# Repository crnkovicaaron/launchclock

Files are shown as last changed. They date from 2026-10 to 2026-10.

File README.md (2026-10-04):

# Rocket Launch Countdown Clock
A standalone digital countdown clock for rocket launches.
It displays countdown and mission elapsed time, is controlled entirely using a keypad, and requires no external computer or network.
It is built around an ATmega328P microcontroller, DS3231 real-time clock, and MAX7219-driven 7-segment and dot matrix displays.

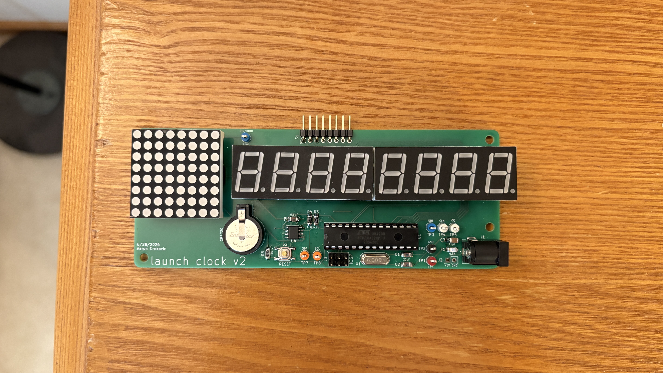
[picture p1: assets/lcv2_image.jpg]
Finished board photo

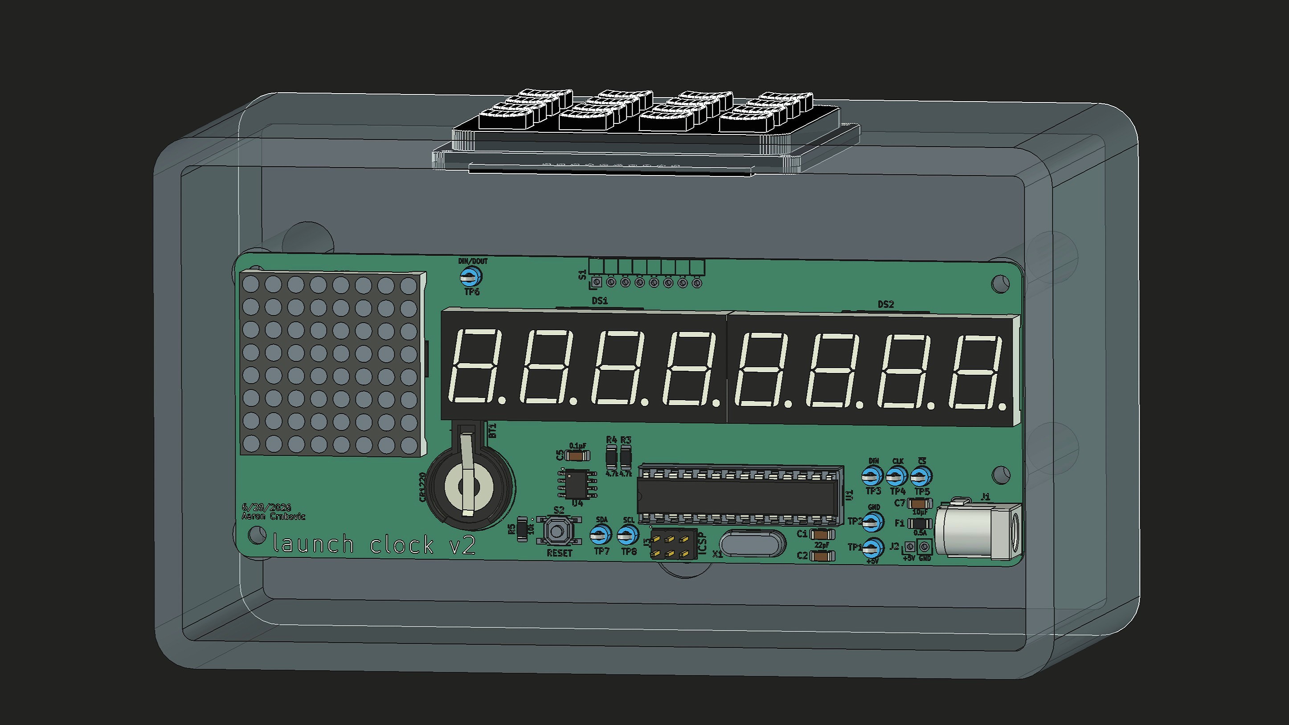
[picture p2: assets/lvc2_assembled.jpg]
Version 2 Box prototype


## Features
- LED Displays: 7-segment for time and dot matrix for mode/status glyphs
- Fully keypad-driven UI
- Launch and current time/date setting (including launch date nudging)
- Countdown pausing
- Low-power sleep mode
- Display brightness control
- Configurable countdown time display format
- Error handling including invalid inputs and RTC power loss

## Hardware
Custom PCB designed in KiCad around an ATmega328P microcontroller.

Key components: 
- **MCU**: ATmega328P
- **RTC**: DS3231M with CR1220 battery backup
- **Displays**: MAX7219-driven dual 4-digit 7-segment (5641AS) and 8x8 dot matrix (1088AS)
- **Input**: 4x4 matrix keypad
- **Power**: 5V DC via 5.5x2.1mm barrel jack (or solder pads to enclosure-mounted barrel jack)
- **Communication**: I²C (RTC) and SPI (display drivers & ISP)
- **Assembly**: Hand soldered; uses both THD and SMD components
- **Enclosure**: Custom 3D printed FreeCAD enclosure is WIP

KiCad schematic and PCB files are under the 'hardware/' directory. Assorted photos can be found under the 'assets/' directory.

Status: Version 2 is completed and functional. Version 3 is WIP.

## Firmware
Written in Arduino C++ (AVR) for the ATmega328P (Arduino Uno).

The firmware implements a keypad-driven state machine that manages countdown/MET display, time/date setting, pause, brightness, sleep, and error handling.

Key elements:

- **Libraries**: RTClib (DS3231), Keypad, LedControl (MAX7219), EEPROM, plus AVR sleep/power utilities
- **Architecture**: Event-driven keypad handling and periodic 1-second time updates; use of mode flags for UI states
- **Displays**: Dual MAX7219 display control with PROGMEM bitmaps
- **Persistence**: Launch time/date stored in EEPROM
- **Power**: Full power-down sleep mode woken by keypad pin-change interrupt
- **Robustness**: Input validation, RTC power-loss detection, and dedicated error states

Source is a single sketch organized into functional blocks (display, input, timekeeping, power, UI modes). Programming is performed via the board's ISP header.

## Development History
### Initial Prototype
This Arduino breadboard prototype was an MVP with the singular goal of counting down to the Artemis II launch, with all work being completed entirely the day prior. It has the 7-segment displays wired directly to an Arduino Mega, uses a DS1307 RTC breakout board, and lacks any inputs.

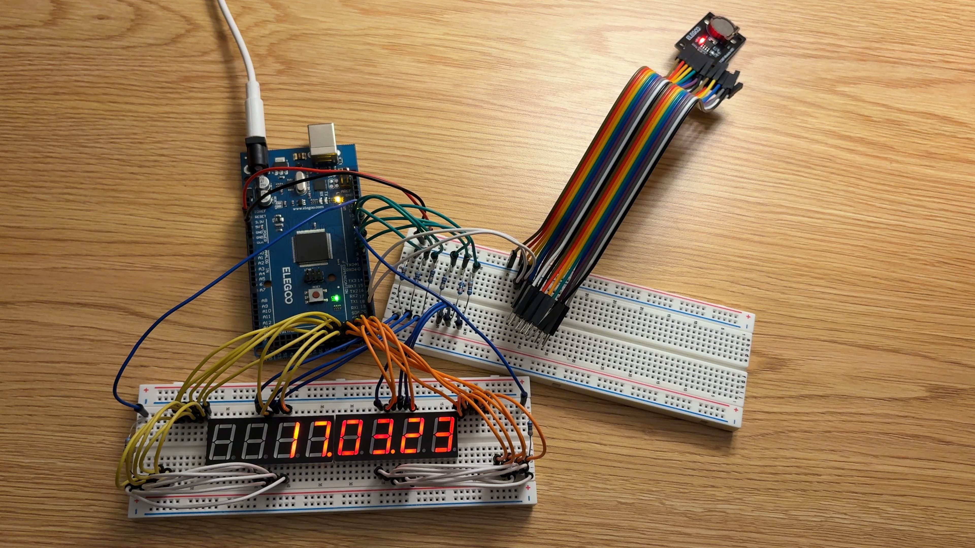
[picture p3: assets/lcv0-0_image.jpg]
Initial prototype photo


### Revised Prototype
This revised prototype contains around a month of additions and improvements to the initial prototype. These include the addition of keypad inputs (out of frame), a dot matrix display, and corrected/improved display wiring. The vast majority of the time since the initial prototype was spent programming the firmware.

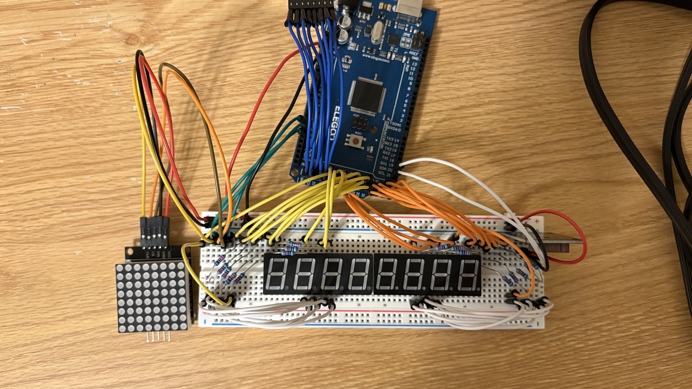
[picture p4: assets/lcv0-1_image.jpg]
Revised prototype photo


### Version 1 PCB
This custom 2-layer PCB mounts directly to an Arduino Mega using header pins, and the 7-segment displays mount to the board. With exception to the SMD resistors, there are essentially no changes to the circuit or its components between the revised prototype and the version 1 board. The main goal of this design was to become familiar with KiCad and PCB design.

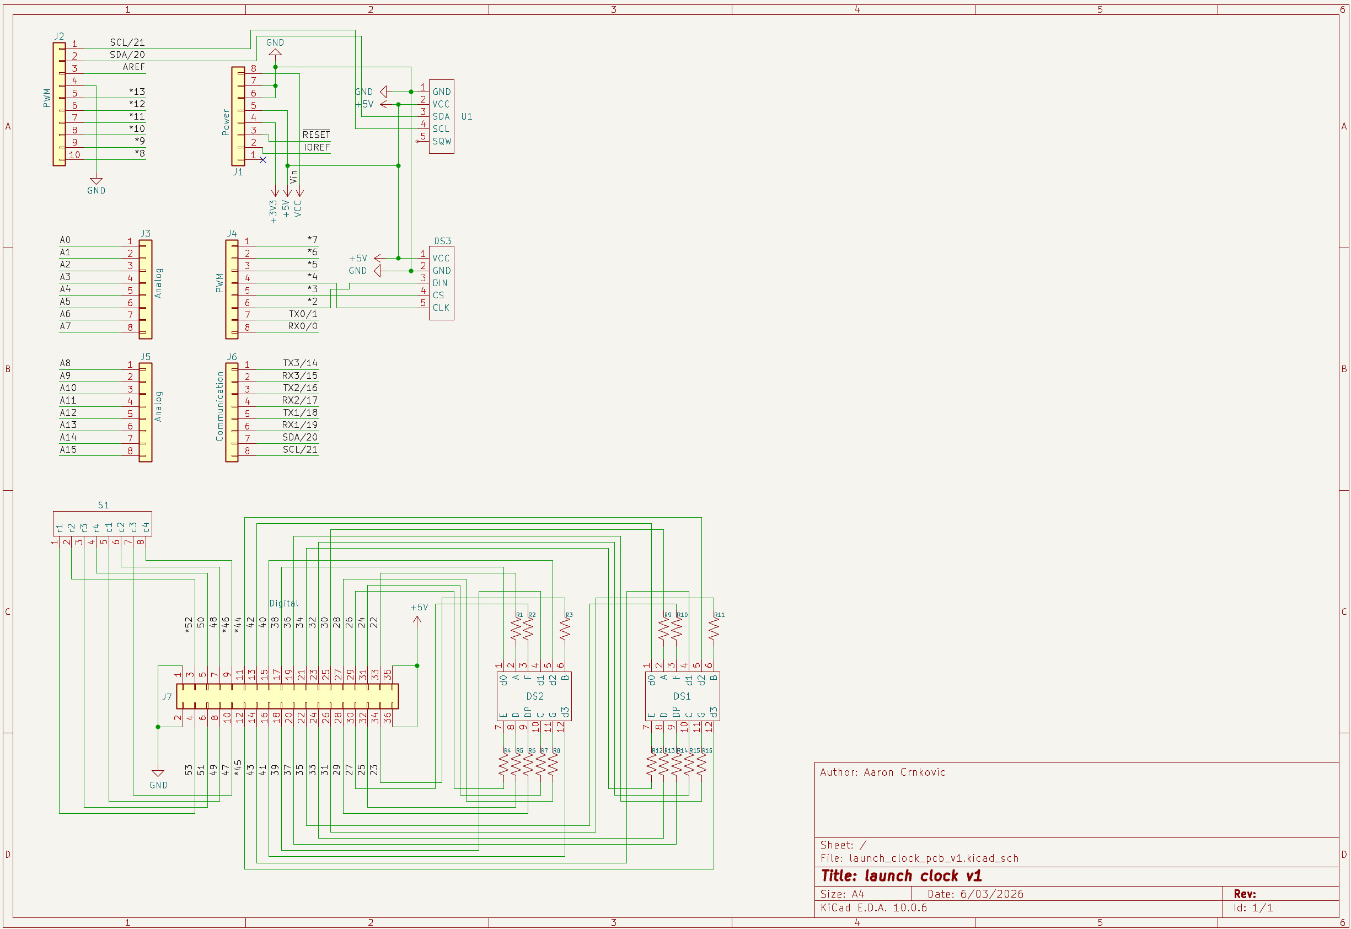
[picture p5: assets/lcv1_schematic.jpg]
Version 1 schematic

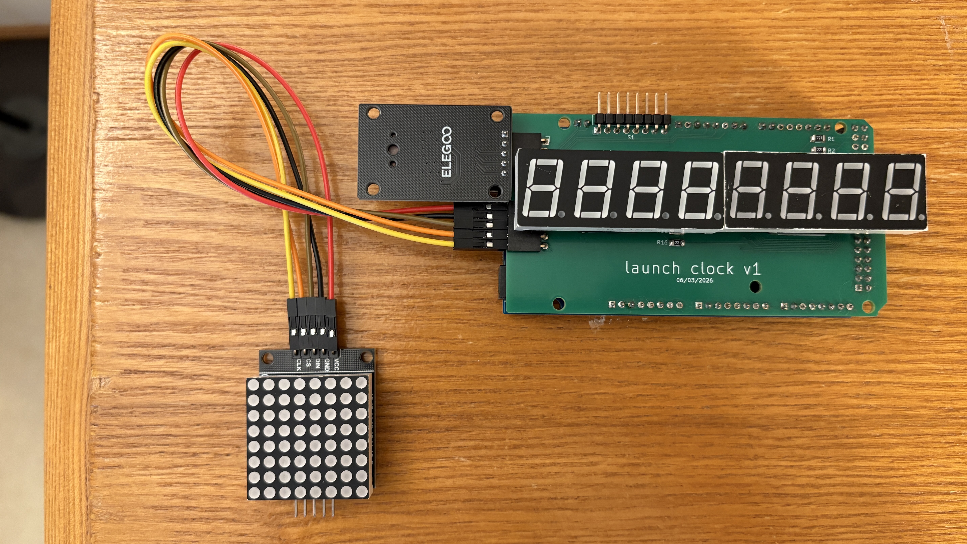
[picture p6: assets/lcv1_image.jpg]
Version 1 image


### Version 2 PCB
The main goal of this version was to eliminate the Arduino and breakout boards by integrating all necessary functionality onto the board itself. This includes driving the 7-segment displays with a MAX7219 in the same manner as the dot matrix to allow the use of an MCU that is easier to solder by hand (instead of the ATmega2560 used on the Arduino Mega). The board is still 2-layers, programming is done via the ISP header, and numerous test points were integrated for troubleshooting and experimentation.

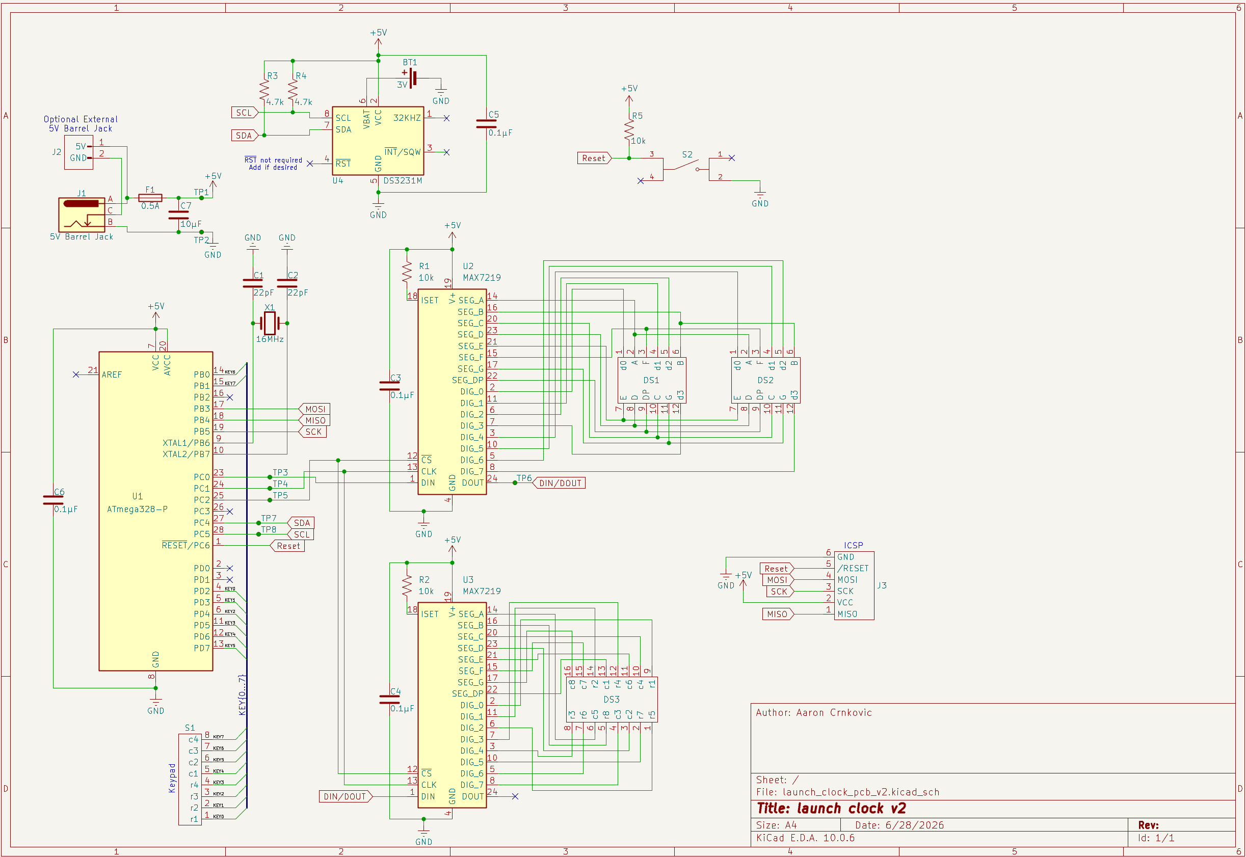
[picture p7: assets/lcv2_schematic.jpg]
Version 2 schematic

Version 2 image

### Version 3 PCB (Work in Progress)
In this version, the barrel jack is superseded by a USB-C port with power and USB 2.0 data functionality. The MCU and display drivers use surface-mount packages in favor of through holes and most passive components are downsized to 0603 parts compared to the 1206 parts on version 2, allowing the total board area to be reduced by 28% compared to version 2. The board was designed to reduce EMI (mainly radiated), which includes switching to a 4-layer board. The revision also addresses numerous smaller issues with the version 2 board, including a soft but audible whine.

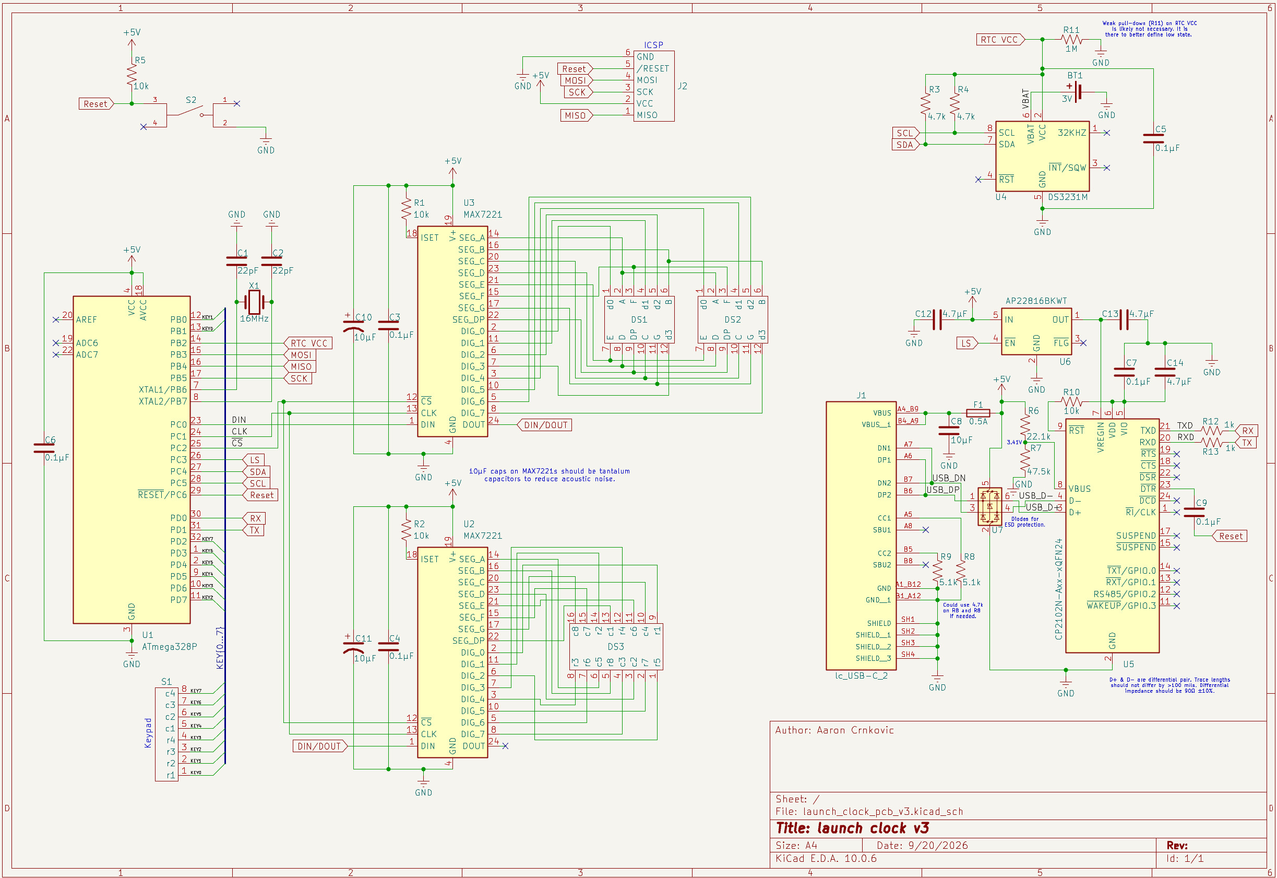
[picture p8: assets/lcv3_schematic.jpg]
Version 3 schematic

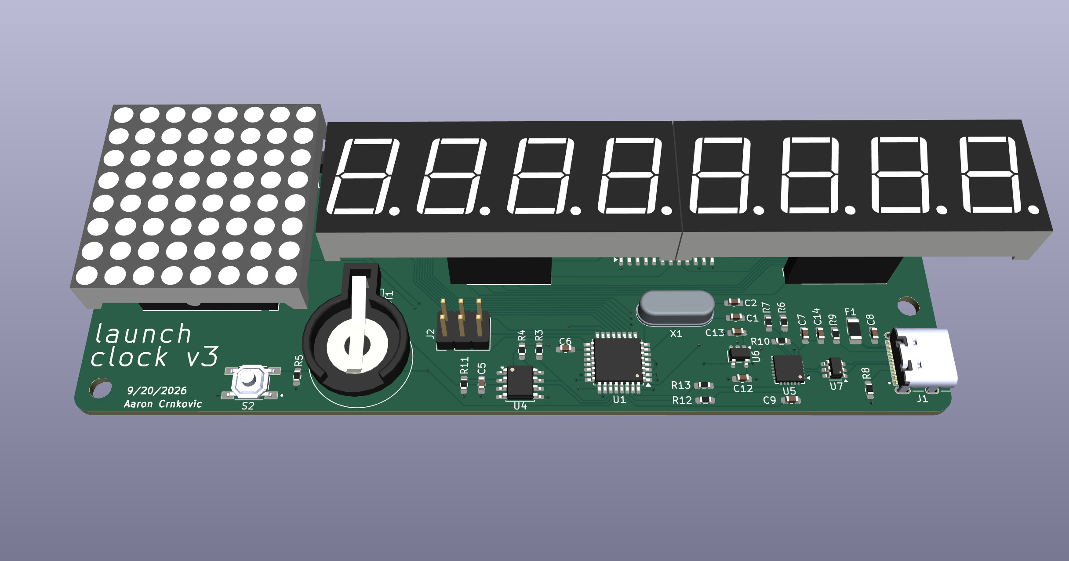
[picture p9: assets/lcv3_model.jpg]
Version 3 KiCad render


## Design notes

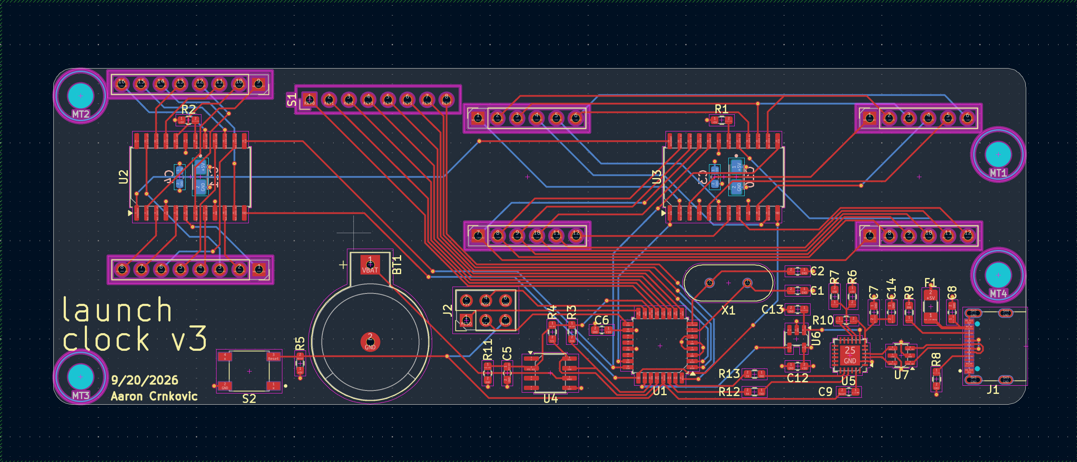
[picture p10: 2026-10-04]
assets/lcv3_pcb.jpg

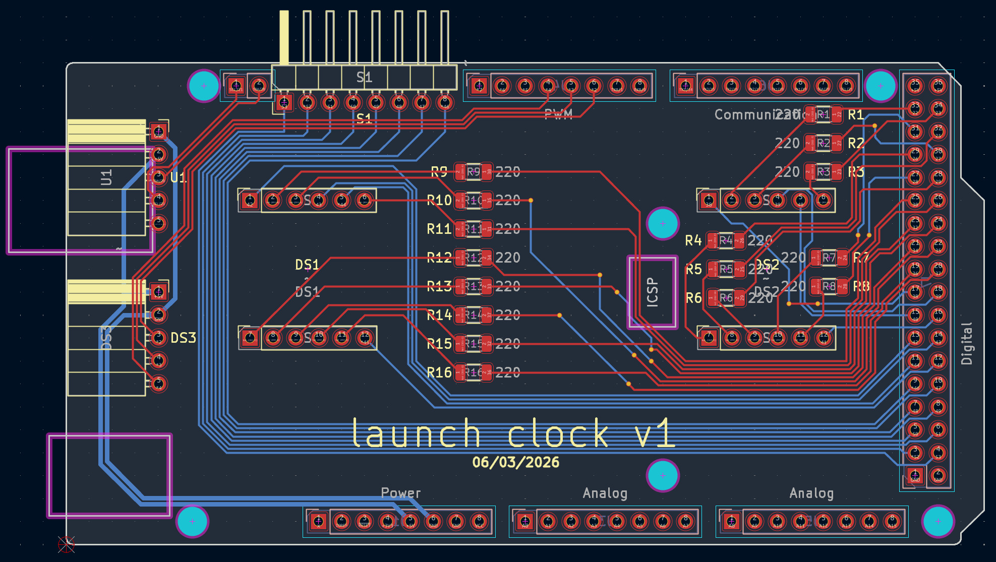
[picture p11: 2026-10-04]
assets/lcv1_pcb.jpg

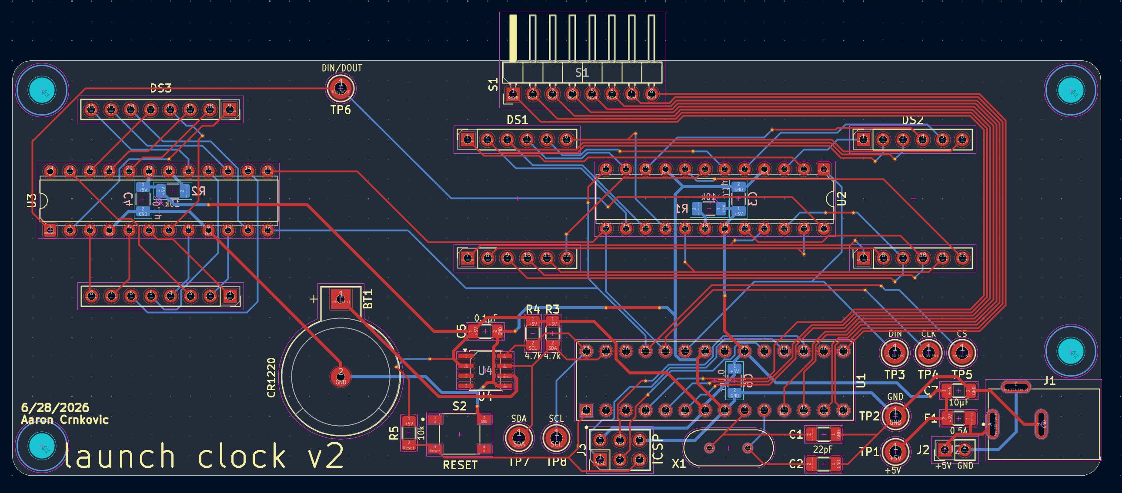
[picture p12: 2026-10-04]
assets/lcv2_pcb.jpg

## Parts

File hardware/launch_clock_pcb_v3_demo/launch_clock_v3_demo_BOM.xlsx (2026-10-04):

Reference | Qty | Value | Footprint | DKPN | Datasheet
BT1 | 1 | 3V | Battery:BatteryHolder_Keystone_500 | 36-500-ND | file:///C:/Users/Aaron%20Crnkovic/Downloads/500%20(1).PDF |  |  |  |  | EN | DKPN | Part | Board Qty | Order Qty | Part Cost | Part Tariff | Net Cost | Net Tariff | Tax | Total Cost | Board Cost | Sales Tax: | 7.50%
C1,C2 | 2 | 22pF | Capacitor_SMD:C_0603_1608Metric_Pad1.08x0.95mm_HandSolder | 490-4942-1-ND | https://pim.murata.com/asset/pim4/ceramicCapacitorSMD/GCM1885C2A220JA16-01A-EN_PDF_CERAMICCAPACITORSMD |  |  |  |  | TRUE | 490-4942-1-ND | 22pF Ceramic Capacitor | 2 | 10 | $0.04 | $0.00463 | $0.44 | $0.05 | $0.04 | $0.49 | $0.10
C3,C4,C5,C6,C7,C9 | 6 | 0.1µF | Capacitor_SMD:C_0603_1608Metric_Pad1.08x0.95mm_HandSolder | 490-14359-1-ND | https://pim.murata.com/asset/pim4/ceramicCapacitorSMD/GCM188R91E104KA37-04A-EN_PDF_CERAMICCAPACITORSMD |  |  |  |  | TRUE | 490-14359-1-ND | 0.1µF Ceramic Capacitor | 6 | 20 | $0.08 | $0.01 | $1.64 | $0.17 | $0.14 | $1.81 | $0.54
C8 | 1 | 10µF | Capacitor_SMD:C_0603_1608Metric_Pad1.08x0.95mm_HandSolder | 490-10475-1-ND | https://mm.digikey.com/Volume0/opasdata/d220001/medias/docus/8942/490_Chip_Multilayer_CAT2021_MLCC.pdf |  |  |  |  | TRUE | 490-10475-1-ND | 10µF Ceramic Capacitor | 1 | 10 | $0.07 | $0.01 | $0.72 | $0.07 | $0.06 | $0.79 | $0.08
C10,C11 | 2 | 10µF | launch_clock_footprints:lc_10µF_tantalum | 478-11220-1-ND | https://datasheets.kyocera-avx.com/TAJ_AUTO.pdf |  |  |  |  | TRUE | 478-11220-1-ND | 10µF Tantalum Capacitor | 2 | 10 | $0.31 | $0.02 | $3.10 | $0.25 | $0.25 | $3.35 | $0.67
C12,C13,C14 | 3 | 4.7µF | Capacitor_SMD:C_0603_1608Metric_Pad1.08x0.95mm_HandSolder | 490-7203-1-ND | https://mm.digikey.com/Volume0/opasdata/d220001/medias/docus/8942/Chip_Multilayer_CAT2021_MLCC.pdf |  |  |  |  | TRUE | 490-7203-1-ND | 4.7µF Ceramic Capacitor | 3 | 15 | $0.14 | $0.01 | $2.11 | $0.22 | $0.18 | $2.34 | $0.47
DS1,DS2 | 2 | 1x6 female headers | launch_clock_footprints:launch_clock_7seg | 2223-SSK02-FPH-254-A6-ND | https://www.sameskydevices.com/product/resource/ssk02-fph-254.pdf |  |  |  |  | TRUE | 2223-UJ20-C-H-G-SMT-1-P16-TRCT-ND | USB-C 2.0 Receptacle | 1 | 4 | $0.49 | $0.13 | $1.96 | $0.51 | $0.19 | $2.47 | $0.62
DS3 | 1 | 1x8 female headers | launch_clock_footprints:1088AS_footprint | 2223-SSK02-FPH-254-A8-ND | https://www.sameskydevices.com/product/resource/ssk02-fph-254.pdf |  |  |  |  | TRUE | 2223-TS18-5-25-SL-260-SMT-TRCT-ND | Push Button Switch (Reset) | 1 | 5 | $0.20 | $0.05 | $1.00 | $0.24 | $0.09 | $1.24 | $0.25
F1 | 1 | 0.5A | Fuse:Fuse_1206_3216Metric_Pad1.42x1.75mm_HandSolder | 13-JB12F5000RCT-ND | https://mm.digikey.com/Volume0/opasdata/d220001/medias/docus/8834/JB12F.pdf |  |  |  |  | TRUE | ATMEGA328PB-AU-ND | ATMEGA328PB | 1 | 4 | $1.63 | $0.12 | $6.52 | $0.49 | $0.53 | $7.01 | $1.75
J1 | 1 | lc_USB-C_2 | launch_clock_footprints:lc_USB-C_2 | 2223-UJ20-C-H-G-SMT-1-P16-TRCT-ND | https://www.sameskydevices.com/product/resource/uj20-c-h-g-smt-1-p16-tr.pdf |  |  |  |  | TRUE | 175-DS3231MZ+TRLCT-ND | DS3231MZ [8 pin] | 1 | 2 | $13.85 | $1.11 | $27.70 | $2.22 | $2.24 | $29.92 | $14.96
J2 | 1 | ICSP | Connector_PinHeader_2.54mm:PinHeader_2x03_P2.54mm_Vertical |  |  |  |  |  |  | TRUE | 336-5887-ND | CP2102N [24 pin] | 1 | 3 | $5.15 | $2.06 | $15.45 | $6.18 | $1.62 | $21.63 | $7.21
R1,R2,R5,R10 | 4 | 10k | Resistor_SMD:R_0603_1608Metric_Pad0.98x0.95mm_HandSolder |  |  |  |  |  |  | TRUE | 31-AP22816BKWT-7CT-ND | AP22816B (load switch) | 1 | 5 | $0.31 | $0.12 | $1.55 | $0.58 | $0.16 | $2.13 | $0.43
R3,R4 | 2 | 4.7k | Resistor_SMD:R_0603_1608Metric_Pad0.98x0.95mm_HandSolder |  |  |  | Height | Width | Area | TRUE | 497-5235-1-ND | USBLC6 (ESD diodes) | 1 | 4 | $0.54 | $0.24 | $2.16 | $0.97 | $0.23 | $3.13 | $0.78
R6 | 1 | 22.1k | Resistor_SMD:R_0603_1608Metric_Pad0.98x0.95mm_HandSolder |  |  | V2: | 2.1 | 5.5 | 11.55 | TRUE | 36-500-ND | Battery Holder [CR1220] | 1 | 3 | $1.30 | $0.00 | $3.90 | $0.00 | $0.29 | $3.90 | $1.30
R7 | 1 | 47.5k | Resistor_SMD:R_0603_1608Metric_Pad0.98x0.95mm_HandSolder |  |  | V3: | 1.676 | 4.965 | 8.32134 | TRUE | 2223-SSK02-FPH-254-A6-ND | 1x6 2.54mm [Str-F] (7-seg) | 4 | 10 | $0.31 | $0.09 | $3.06 | $0.86 | $0.29 | $3.92 | $1.57
R8,R9 | 2 | 5.1k | Resistor_SMD:R_0603_1608Metric_Pad0.98x0.95mm_HandSolder | P5.10KHCT-ND | https://industrial.panasonic.com/cdbs/www-data/pdf/RDA0000/AOA0000C304.pdf |  |  |  | 72.04623377% | TRUE | 2223-SSK02-FPH-254-A8-ND | 1x8 2.54mm [Str-F] (Mtrx) | 2 | 4 | $0.40 | $0.11 | $1.60 | $0.45 | $0.15 | $2.05 | $1.02
R11 | 1 | 1M | Resistor_SMD:R_0603_1608Metric_Pad0.98x0.95mm_HandSolder |  |  |  |  |  |  | TRUE | P5.10KHCT-ND | 5.1kΩ Resistor [0603] | 2 | 10 | $0.04 | $0.01 | $0.39 | $0.10 | $0.04 | $0.49 | $0.10
R12,R13 | 2 | 1k | Resistor_SMD:R_0603_1608Metric_Pad0.98x0.95mm_HandSolder |  |  |  |  |  |  | TRUE | 1528-3844-ND | 4x4 Keypad | 1 | 1 | $5.95 | $0.00 | $5.95 | $0.00 | $0.45 | $5.95 | $5.95
S1 | 1 | keypad | Connector_PinHeader_2.54mm:PinHeader_1x08_P2.54mm_Horizontal |  |  |  |  |  |  |  |  |  |  |  |  |  | $79.26 | $13.36 | $6.95 | $104.55 | $44.74
S2 | 1 | lc_reset_button | launch_clock_footprints:lc_reset_button | 2223-TS18-5-25-SL-260-SMT-TRCT-ND | https://www.sameskydevices.com/product/resource/ts18.pdf |  |  |  |  | TRUE | amazon_MAX7221_option1 (https://www.amazon.com/10PCS-MAX7221CWG-MAX7221CW-MAX7221C-MAX7221/dp/B0DRFMGX6S) | MAX7221 [10pcs] | 2 | 10 | $0.95 | $0.00 | $9.55 | $0.00 | $0.72 | $10.27 | $2.05
U1 | 1 | ATmega328P | Package_QFP:TQFP-32_7x7mm_P0.8mm | ATMEGA328PB-AU-ND | https://ww1.microchip.com/downloads/en/DeviceDoc/40001907A.pdf |  |  |  |  | FALSE | amazon_MAX7221_option2 (https://www.amazon.com/dp/B09PLPT7B7?lv=shuf&channelId=704&plpRedirect=mhFallback) | MAX7221 [5pcs] | 2 | 5 | $1.51 | $0.00 | $7.53 | $0.00 | $0.56 | $8.09 | $3.24
U2,U3 | 2 | MAX7221 | Package_SO:SOIC-24W_7.5x15.4mm_P1.27mm | N/A | https://datasheets.maximintegrated.com/en/ds/MAX7219-MAX7221.pdf |  |  |  |  | FALSE | amazon_MAX7221_option3 (https://www.amazon.com/MAX7221CWG-SOP24-MAX7221-SOP-5PCS/dp/B0HDCJZJ91) | MAX7221 [5pcs] | 2 | 5 | $1.71 | $0.00 | $8.57 | $0.00 | $0.64 | $9.21 | $3.69
U4 | 1 | DS3231M | Package_SO:SOIC-8_3.9x4.9mm_P1.27mm | 175-DS3231MZ+TRLCT-ND | http://datasheets.maximintegrated.com/en/ds/DS3231M.pdf |  |  |  |  | TRUE | PCBWay | launch_clock_pcb_v3 [5pcs] | 1 | 5 | $13.52 | (unkn) | $67.62 | (unkn) | $5.07 | $85.39 | $17.08
U5 | 1 | CP2102N-Axx-xQFN24 | Package_DFN_QFN:QFN-24-1EP_4x4mm_P0.5mm_EP2.6x2.6mm | 336-5887-ND | https://www.silabs.com/documents/public/data-sheets/cp2102n-datasheet.pdf |  |  |  |  | FALSE | OSHPark | launch_clock_pcb_v3 [3pcs] | 1 | 3 | $28.40 | $0.00 | $85.20 | $0.00 | $6.39 | $91.59 | $30.53
U6 | 1 | AP22816BKWT | Package_TO_SOT_SMD:SOT-23-5 | 31-AP22816BKWT-7CT-ND | https://www.diodes.com/assets/Datasheets/AP22816_17_18.pdf |  |  |  |  |  |  |  |  |  |  |  |  |  |  | $200.20 | $63.87
U7 | 1 | USBLC6-2SC6 | Package_TO_SOT_SMD:SOT-23-6 | 497-5235-1-ND | https://www.st.com/resource/en/datasheet/usblc6-2.pdf
X1 | 1 | 16MHz | launch_clock_footprints:16MHz_resonator | [300-6034-ND] - UNEEDED | https://cfd.citizen.co.jp/cms/cfd/pdf/english/HC-49_U-S_E.pdf

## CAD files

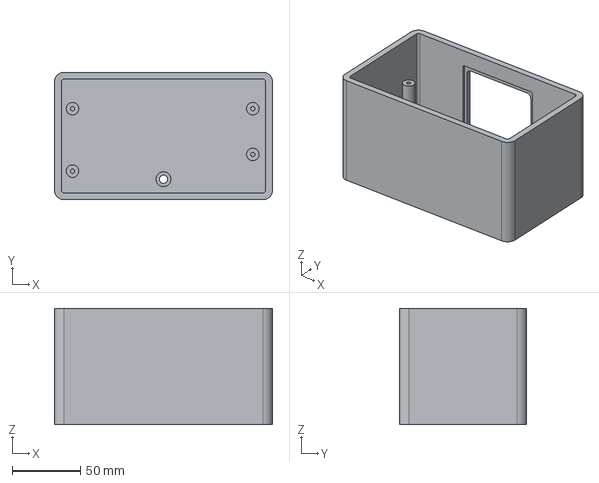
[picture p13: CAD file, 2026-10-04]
mechanical/launch_clock_v2_box.step
159.7 x 93.3 x 85.0 mm

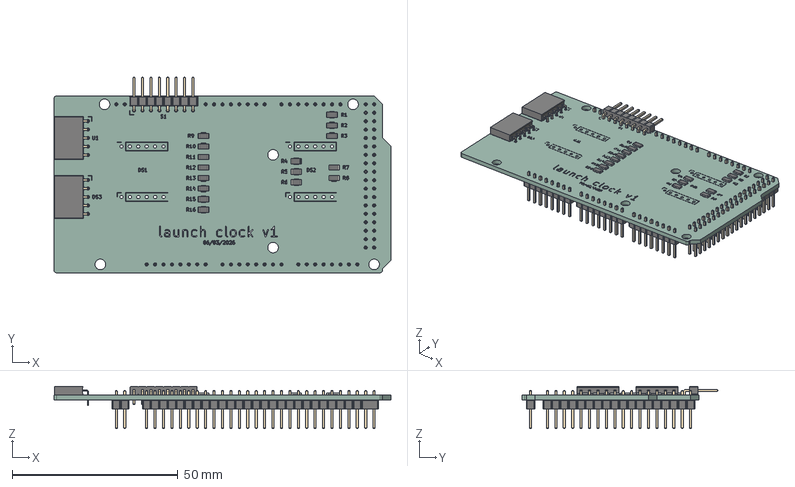
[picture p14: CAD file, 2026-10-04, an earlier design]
hardware/launch_clock_pcb_v1/.step
101.6 x 59.0 x 12.8 mm
R_1206_3216Metric x 16
PinHeader_1x08_P254mm_Horizontal
PinSocket_1x05_P2.54mm_Horizontal x 2
PinHeader_2x18_P254mm_Vertical
PinHeader_1x08_P254mm_Vertical x 5
PinHeader_1x02_P254mm_Vertical
launch_clock_pcb_v1_silkscreen x 2
launch_clock_pcb_v1_PCB

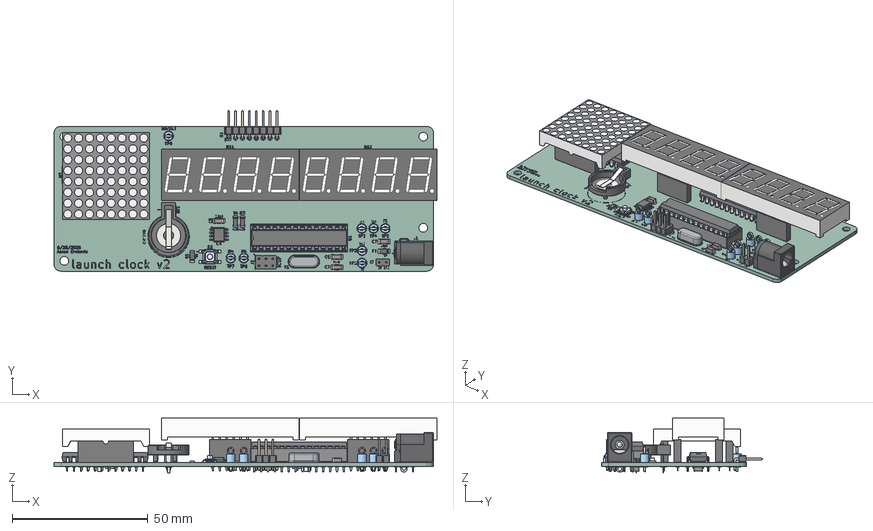
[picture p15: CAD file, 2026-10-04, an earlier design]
hardware/launch_clock_pcb_v2/.step
140.9 x 59.1 x 20.2 mm
TestPoint_Keystone_5005_5009_Compact_cp x 8
PinHeader_1x08_P254mm_Horizontal
SOIC-8_3.9x4.9mm_P1.27mm
Keystone_500
C_1206_3216Metric x 7
Fuse_1206_3216Metric
R_1206_3216Metric x 5
ED281DT
DIP-28_W7.62mm
DIP-24_W7.62mm x 2
PinHeader_1x02_P254mm_Vertical
PinSocket_1x06_P2.54mm_Vertical x 4
4-7-display v2 x 2
CUI_DEVICES_TS18-5-25-SL-260-SMT-TR
PinHeader_2x03_P254mm_Vertical
PinSocket_1x08_P2.54mm_Vertical x 2
1088-led_array
1088-shell
1088-lead x 16
1088-bottom-fill^1088
launch_clock_pcb_v2_pad
launch_clock_pcb_v2_silkscreen x 2
launch_clock_pcb_v2_PCB

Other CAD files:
mechanical/launch_clock_v2_box.FCStd

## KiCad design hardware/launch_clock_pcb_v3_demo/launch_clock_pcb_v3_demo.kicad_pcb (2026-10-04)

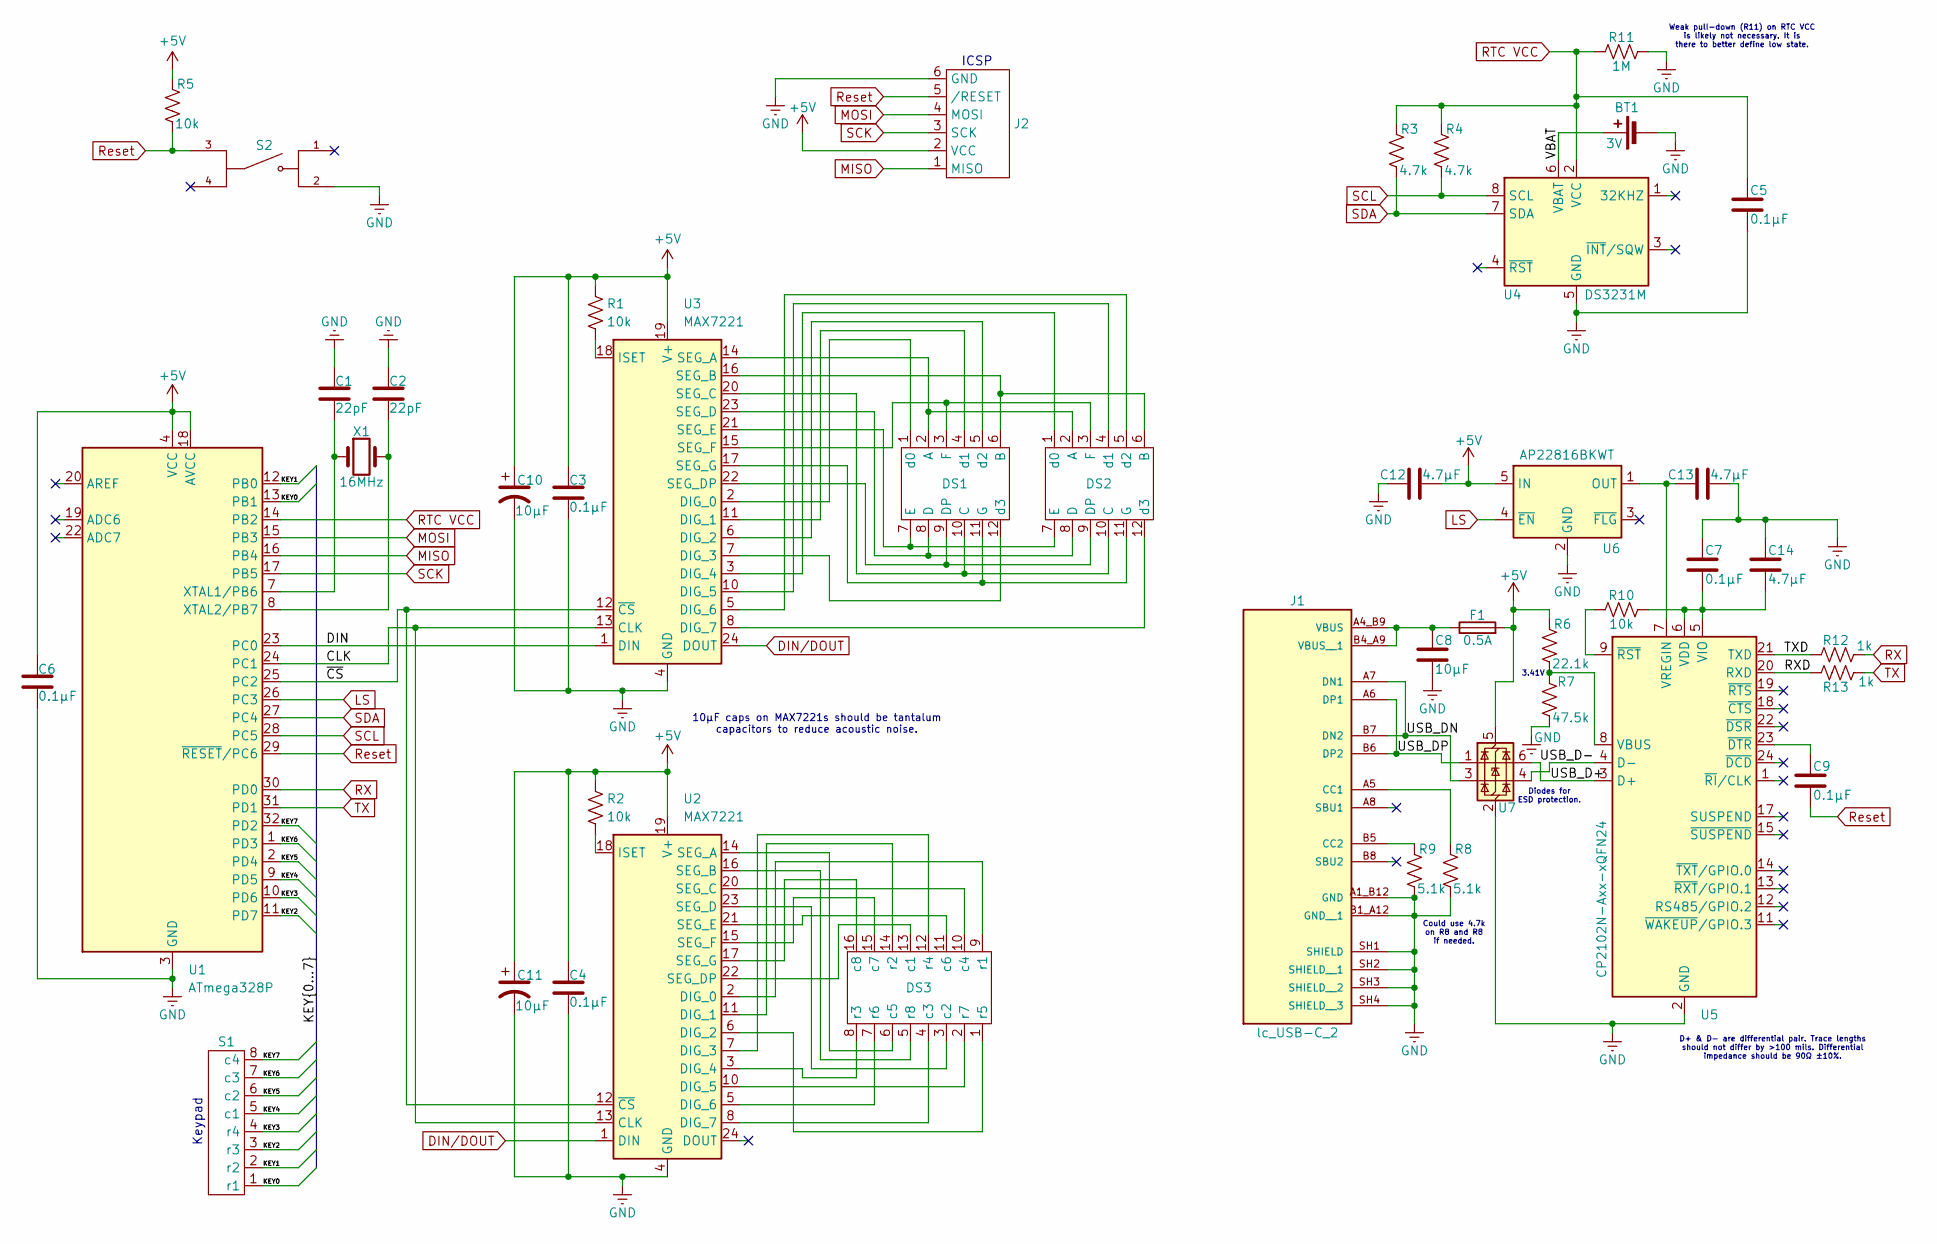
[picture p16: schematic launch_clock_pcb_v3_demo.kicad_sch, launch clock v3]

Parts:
BT1: 3V; BatteryHolder_Keystone_500
C1, C2: 22pF; C_0603_1608Metric_Pad1.08x0.95mm_HandSolder
C3, C4, C5, C6, C7, C9: 0.1µF; C_0603_1608Metric_Pad1.08x0.95mm_HandSolder
C8: 10µF; C_0603_1608Metric_Pad1.08x0.95mm_HandSolder
C10, C11: 10µF; lc_10µF_tantalum
C12, C13, C14: 4.7µF; C_0603_1608Metric_Pad1.08x0.95mm_HandSolder
DS1, DS2: launch_clock_7seg
DS3: 1088AS_footprint
F1: 0.5A; Fuse_1206_3216Metric_Pad1.42x1.75mm_HandSolder
J1: lc_USB-C_2; PARTREV 1.0
J2: PinHeader_2x03_P2.54mm_Vertical
R1, R2, R5, R10: 10k; R_0603_1608Metric_Pad0.98x0.95mm_HandSolder
R3, R4: 4.7k; R_0603_1608Metric_Pad0.98x0.95mm_HandSolder
R6: 22.1k; R_0603_1608Metric_Pad0.98x0.95mm_HandSolder
R7: 47.5k; R_0603_1608Metric_Pad0.98x0.95mm_HandSolder
R8, R9: 5.1k; R_0603_1608Metric_Pad0.98x0.95mm_HandSolder
R11: 1M; R_0603_1608Metric_Pad0.98x0.95mm_HandSolder
R12, R13: 1k; R_0603_1608Metric_Pad0.98x0.95mm_HandSolder
S1: PinHeader_1x08_P2.54mm_Horizontal
S2: lc_reset_button; PARTREV 1.02
U1: ATmega328P; TQFP-32_7x7mm_P0.8mm
U2, U3: MAX7221; SOIC-24W_7.5x15.4mm_P1.27mm
U4: DS3231M; SOIC-8_3.9x4.9mm_P1.27mm
U5: CP2102N-Axx-xQFN24; QFN-24-1EP_4x4mm_P0.5mm_EP2.6x2.6mm
U6: AP22816BKWT; SOT-23-5
U7: USBLC6-2SC6; SOT-23-6
X1: 16MHz; 16MHz_resonator

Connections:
+5V: C3.1, C4.1, C6.1, C10.1, C11.1, C12.2, F1.2, J2.2 (VCC), R1.1, R2.1, R5.1, R6.1, U1.4 (VCC), U1.6 (VCC), U1.18 (AVCC), U2.19 (V+), U3.19 (V+), U6.5 (IN), U7.5 (VBUS)
/CLK: U1.24 (PC1), U2.13 (CLK), U3.13 (CLK)
/DIN: U1.23 (PC0), U3.1 (DIN)
/KEY0: S1.1 (r1), U1.13 (PB1)
/KEY1: S1.2 (r2), U1.12 (PB0)
/KEY2: S1.3 (r3), U1.11 (PD7)
/KEY3: S1.4 (r4), U1.10 (PD6)
/KEY4: S1.5 (c1), U1.9 (PD5)
/KEY5: S1.6 (c2), U1.2 (PD4)
/KEY6: S1.7 (c3), U1.1 (PD3)
/KEY7: S1.8 (c4), U1.32 (PD2)
/RXD: R13.1, U5.20 (RXD)
/TXD: R12.1, U5.21 (TXD)
/USB_D+: U5.3 (D+), U7.6 (I/O1)
/USB_D-: U5.4 (D-), U7.4 (I/O2)
/USB_DN: J1.A7 (DN1), J1.B7 (DN2), U7.3 (I/O2)
/USB_DP: J1.A6 (DP1), J1.B6 (DP2), U7.1 (I/O1)
/VBAT: BT1.1 (+), U4.6 (VBAT)
/~CS: U1.25 (PC2), U2.12 (~CS), U3.12 (~CS)
DIN/DOUT: U2.1 (DIN), U3.24 (DOUT)
GND: BT1.2 (-), C1.1, C2.1, C3.2, C4.2, C5.2, C6.2, C7.1, C8.2, C10.2, C11.2, C12.1, C13.2, C14.1, J1.A1_B12 (GND), J1.B1_A12 (GND__1), J1.SH1 (SHIELD), J1.SH2 (SHIELD__1), J1.SH3 (SHIELD__2), J1.SH4 (SHIELD__3), J2.6 (GND), R7.2, R8.2, R9.2, R11.2, S2.2, U1.3 (GND), U1.5 (GND), U1.21 (GND), U2.4 (GND), U2.9 (GND), U3.4 (GND), U3.9 (GND), U4.5 (GND), U5.2 (GND), U5.25 (GND), U6.2 (GND), U7.2 (GND)
LS: U1.26 (PC3), U6.4 (~EN)
MISO: J2.1 (MISO), U1.16 (PB4)
MOSI: J2.4 (MOSI), U1.15 (PB3)
unnamed: DS1.2 (A), DS2.2 (A), U3.14 (SEG_A)
unnamed: DS1.6 (B), DS2.6 (B), U3.16 (SEG_B)
unnamed: DS1.10 (C), DS2.10 (C), U3.20 (SEG_C)
unnamed: DS1.8 (D), DS2.8 (D), U3.23 (SEG_D)
unnamed: DS1.9 (DP), DS2.9 (DP), U3.22 (SEG_DP)
unnamed: DS1.7 (E), DS2.7 (E), U3.21 (SEG_E)
unnamed: DS1.3 (F), DS2.3 (F), U3.15 (SEG_F)
unnamed: DS1.11 (G), DS2.11 (G), U3.17 (SEG_G)
unnamed: DS1.1 (d0), U3.2 (DIG_0)
unnamed: DS1.4 (d1), U3.11 (DIG_1)
unnamed: DS1.5 (d2), U3.6 (DIG_2)
unnamed: DS1.12 (d3), U3.7 (DIG_3)
unnamed: DS2.1 (d0), U3.3 (DIG_4)
unnamed: DS2.4 (d1), U3.10 (DIG_5)
unnamed: DS2.5 (d2), U3.5 (DIG_6)
unnamed: DS2.12 (d3), U3.8 (DIG_7)
unnamed: DS3.13 (c1), U2.22 (SEG_DP)
unnamed: DS3.3 (c2), U2.23 (SEG_D)
unnamed: DS3.4 (c3), U2.8 (DIG_7)
unnamed: DS3.10 (c4), U2.20 (SEG_C)
unnamed: DS3.6 (c5), U2.14 (SEG_A)
unnamed: DS3.11 (c6), U2.21 (SEG_E)
unnamed: DS3.15 (c7), U2.15 (SEG_F)
unnamed: DS3.16 (c8), U2.17 (SEG_G)
unnamed: DS3.9 (r1), U2.2 (DIG_0)
unnamed: DS3.14 (r2), U2.11 (DIG_1)
unnamed: DS3.8 (r3), U2.3 (DIG_4)
unnamed: DS3.12 (r4), U2.7 (DIG_3)
unnamed: DS3.1 (r5), U2.6 (DIG_2)
unnamed: DS3.7 (r6), U2.5 (DIG_6)
unnamed: DS3.2 (r7), U2.10 (DIG_5)
unnamed: DS3.5 (r8), U2.16 (SEG_B)
unnamed: J1.A5 (CC1), R8.1
unnamed: J1.B5 (CC2), R9.1
unnamed: C8.1, F1.1, J1.A4_B9 (VBUS), J1.B4_A9 (VBUS__1)
unnamed: C1.2, U1.7 (XTAL1/PB6), X1.1
unnamed: C2.2, U1.8 (XTAL2/PB7), X1.2
unnamed: R2.2, U2.18 (ISET)
unnamed: R1.2, U3.18 (ISET)
unnamed: R6.2, R7.1, U5.8 (VBUS)
unnamed: C7.2, C14.2, R10.2, U5.5 (VIO), U5.6 (VDD)
unnamed: C13.1, U5.7 (VREGIN), U6.1 (OUT)
unnamed: C9.1, U5.23 (~DTR)
unnamed: R10.1, U5.9 (~RST)
RTC VCC: C5.1, R3.1, R4.1, R11.1, U1.14 (PB2), U4.2 (VCC)
RX: R12.2, U1.30 (PD0)
Reset: C9.2, J2.5 (/RESET), R5.2, S2.3, U1.29 (~RESET/PC6)
SCK: J2.3 (SCK), U1.17 (PB5)
SCL: R4.2, U1.28 (PC5), U4.8 (SCL)
SDA: R3.2, U1.27 (PC4), U4.7 (SDA)
TX: R13.2, U1.31 (PD1)

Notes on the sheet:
D+ & D- are differential pair. Trace lengths should not differ by >100 mils. Differential impedance should be 90Ω ±10%.
ICSP
Weak pull-down (R11) on RTC VCC is likely not necessary. It is there to better define low state.
10µF caps on MAX7221s should be tantalum capacitors to reduce acoustic noise.
Keypad
Could use 4.7k on R8 and R8 if needed.
Diodes for ESD protection.
3.41V

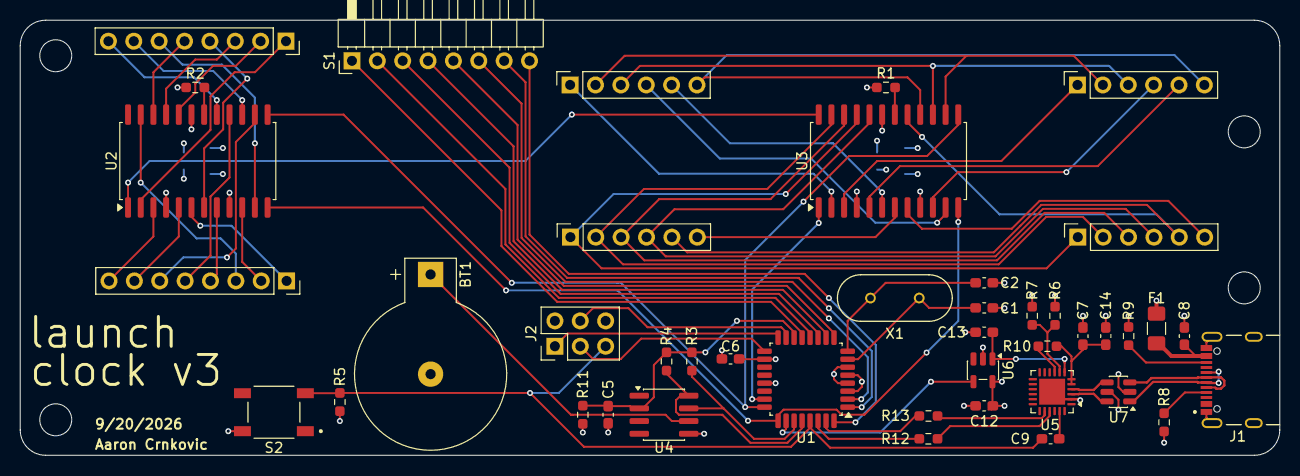
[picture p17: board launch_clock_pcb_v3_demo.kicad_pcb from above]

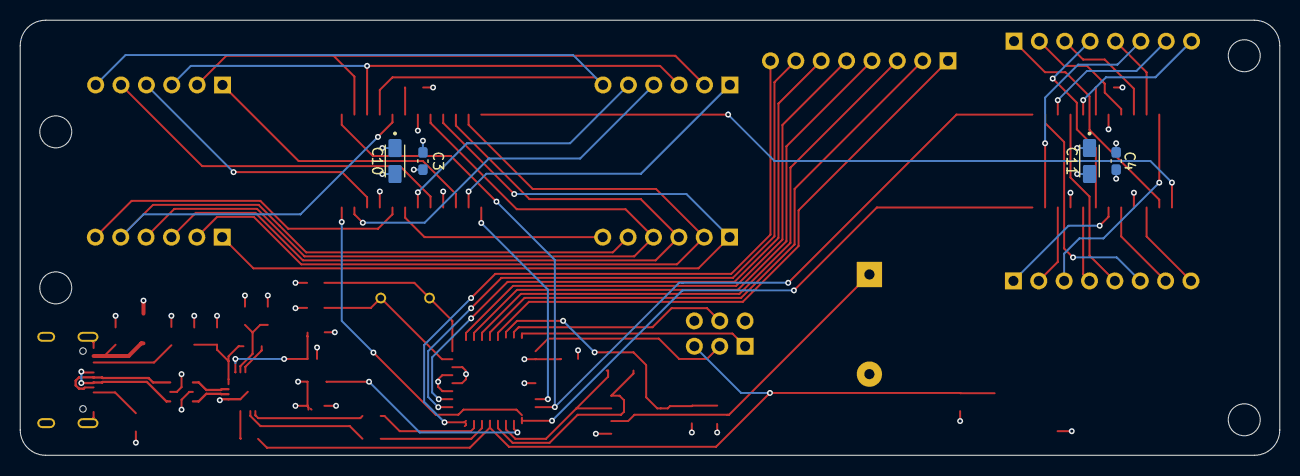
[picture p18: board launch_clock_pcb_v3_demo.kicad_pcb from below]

Board: 4 copper layers, 126.1 x 43.6 mm, 48 parts (4 on the bottom side), 75 nets.

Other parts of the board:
MT3, MT3#2, MT3#3, MT3#4: MountingHole_3.2mm_M3

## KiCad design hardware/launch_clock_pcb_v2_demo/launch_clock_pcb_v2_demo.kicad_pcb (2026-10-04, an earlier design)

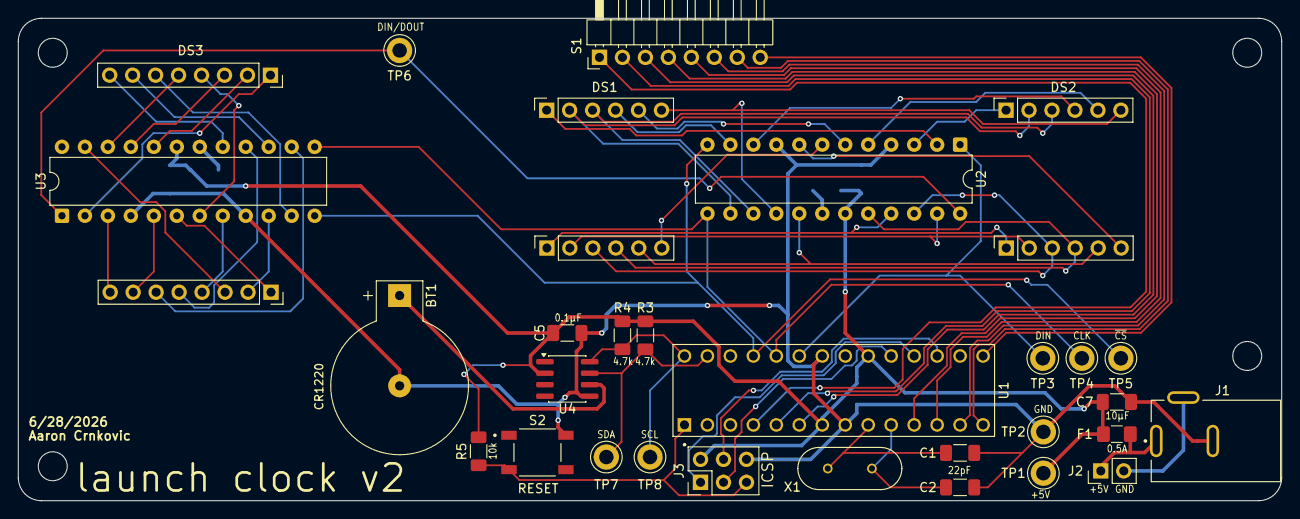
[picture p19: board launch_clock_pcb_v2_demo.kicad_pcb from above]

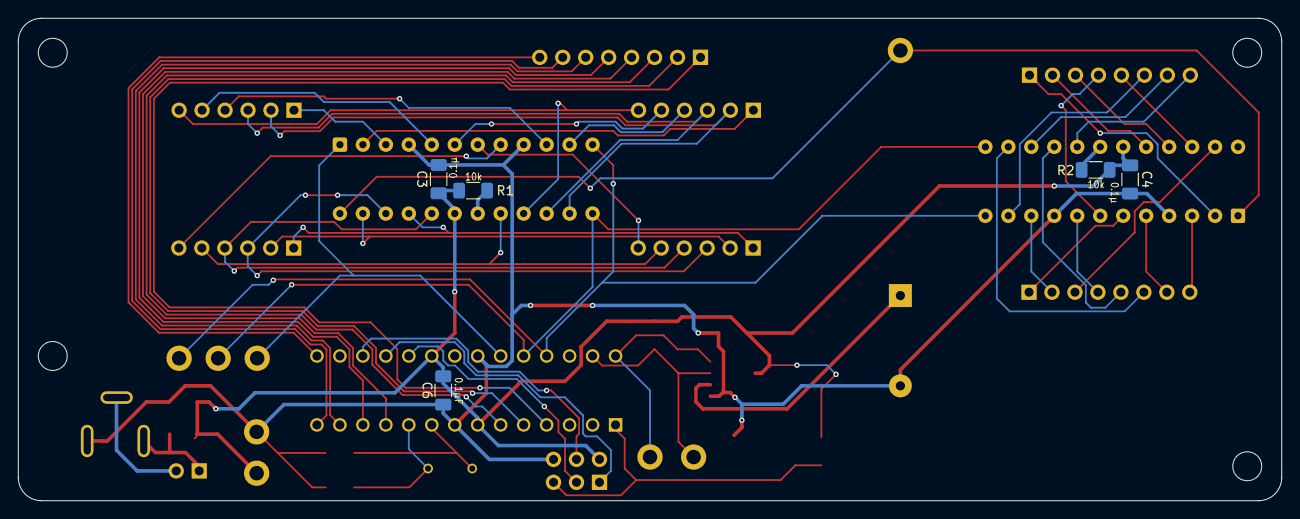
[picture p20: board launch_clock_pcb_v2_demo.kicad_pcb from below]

Board: 2 copper layers, 139.7 x 53.3 mm, 38 parts (5 on the bottom side), 59 nets.

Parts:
BT1: 3V; BatteryHolder_Keystone_500
C1, C2: 22pF; C_1206_3216Metric_Pad1.33x1.80mm_HandSolder
C3, C4, C5, C6: 0.1µF; C_1206_3216Metric_Pad1.33x1.80mm_HandSolder
C7: 10µF; C_1206_3216Metric_Pad1.33x1.80mm_HandSolder
DS1, DS2: launch_clock_7seg
DS3: 1088AS_footprint
F1: 0.5A; Fuse_1206_3216Metric_Pad1.42x1.75mm_HandSolder
J1: 5V Barrel Jack; 5.5x2.1mm_barrel_jack
J2: External 5V Source; PinHeader_1x02_P2.54mm_Vertical
J3: PinHeader_2x03_P2.54mm_Vertical
MT1, MT3, MT4: MountingHole_3.2mm_M3
R1, R2, R5: 10k; R_1206_3216Metric_Pad1.30x1.75mm_HandSolder
R3, R4: 4.7k; R_1206_3216Metric_Pad1.30x1.75mm_HandSolder
S1: PinHeader_1x08_P2.54mm_Horizontal
S2: SW_TS18-5-25-SL-260-SMT-TR; lc_reset_button
TP1, TP2, TP3, TP4, TP5, TP6, TP7, TP8: TestPoint_Small; TestPoint_Keystone_5005-5009_Compact
U1: ATmega328-P; lc_mcu_carriage
U2, U3: MAX7221xNG; DIP-24_W7.62mm
U4: DS3231MZ; SOIC-8_3.9x4.9mm_P1.27mm
X1: 16MHz; 16MHz_resonator

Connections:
+5V: C3.1, C4.1, C5.1, C6.1, C7.1, F1.2, J3.2 (VCC), R1.1, R2.1, R3.1, R4.1, R5.1, TP1.1 (1_1), U1.7 (VCC), U1.20 (AVCC), U2.19 (V+), U3.19 (V+), U4.2 (VCC)
/KEY0: S1.1 (r1), U1.4 (PD2)
/KEY1: S1.2 (r2), U1.5 (PD3)
/KEY2: S1.3 (r3), U1.6 (PD4)
/KEY3: S1.4 (r4), U1.11 (PD5)
/KEY4: S1.5 (c1), U1.12 (PD6)
/KEY5: S1.6 (c2), U1.13 (PD7)
/KEY6: S1.7 (c3), U1.14 (PB0)
/KEY7: S1.8 (c4), U1.15 (PB1)
DIN/DOUT: TP6.1 (1_1), U2.24 (DOUT), U3.1 (DIN)
GND: BT1.2 (-), C1.1, C2.1, C3.2, C4.2, C5.2, C6.2, C7.2, J1.B, J3.6 (GND), S2.2, TP2.1 (1_1), U1.8 (GND), U1.22 (GND), U2.4 (GND), U2.9 (GND), U3.4 (GND), U3.9 (GND), U4.5 (GND)
MISO: J3.1 (MISO), U1.18 (PB4)
MOSI: J3.4 (MOSI), U1.17 (PB3)
unnamed: BT1.1 (+), U4.6 (VBAT)
unnamed: DS1.2 (A), DS2.2 (A), U2.14 (SEG_A)
unnamed: DS1.6 (B), DS2.6 (B), U2.16 (SEG_B)
unnamed: DS1.10 (C), DS2.10 (C), U2.20 (SEG_C)
unnamed: DS1.8 (D), DS2.8 (D), U2.23 (SEG_D)
unnamed: DS1.9 (DP), DS2.9 (DP), U2.22 (SEG_DP)
unnamed: DS1.7 (E), DS2.7 (E), U2.21 (SEG_E)
unnamed: DS1.3 (F), DS2.3 (F), U2.15 (SEG_F)
unnamed: DS1.11 (G), DS2.11 (G), U2.17 (SEG_G)
unnamed: DS1.1 (d0), U2.2 (DIG_0)
unnamed: DS1.4 (d1), U2.11 (DIG_1)
unnamed: DS1.5 (d2), U2.6 (DIG_2)
unnamed: DS1.12 (d3), U2.7 (DIG_3)
unnamed: DS2.1 (d0), U2.3 (DIG_4)
unnamed: DS2.4 (d1), U2.10 (DIG_5)
unnamed: DS2.5 (d2), U2.5 (DIG_6)
unnamed: DS2.12 (d3), U2.8 (DIG_7)
unnamed: DS3.13 (c1), U3.22 (SEG_DP)
unnamed: DS3.3 (c2), U3.23 (SEG_D)
unnamed: DS3.4 (c3), U3.8 (DIG_7)
unnamed: DS3.10 (c4), U3.20 (SEG_C)
unnamed: DS3.6 (c5), U3.14 (SEG_A)
unnamed: DS3.11 (c6), U3.21 (SEG_E)
unnamed: DS3.15 (c7), U3.15 (SEG_F)
unnamed: DS3.16 (c8), U3.17 (SEG_G)
unnamed: DS3.9 (r1), U3.2 (DIG_0)
unnamed: DS3.14 (r2), U3.11 (DIG_1)
unnamed: DS3.8 (r3), U3.3 (DIG_4)
unnamed: DS3.12 (r4), U3.7 (DIG_3)
unnamed: DS3.1 (r5), U3.6 (DIG_2)
unnamed: DS3.7 (r6), U3.5 (DIG_6)
unnamed: DS3.2 (r7), U3.10 (DIG_5)
unnamed: DS3.5 (r8), U3.16 (SEG_B)
unnamed: F1.1, J1.A, J2.1
unnamed: J1.C, J2.2
unnamed: TP3.1 (1_1), U1.23 (PC0), U2.1 (DIN)
unnamed: TP4.1 (1_1), U1.24 (PC1), U2.13 (CLK), U3.13 (CLK)
unnamed: TP5.1 (1_1), U1.25 (PC2), U2.12 (~CS), U3.12 (~CS)
unnamed: C1.2, U1.9 (XTAL1/PB6), X1.1
unnamed: C2.2, U1.10 (XTAL2/PB7), X1.2
unnamed: R1.2, U2.18 (ISET)
unnamed: R2.2, U3.18 (ISET)
Reset: J3.5 (/RESET), R5.2, S2.3, U1.1 (~RESET/PC6)
SCK: J3.3 (SCK), U1.19 (PB5)
SCL: R4.2, TP8.1 (1_1), U1.28 (PC5), U4.8 (SCL)
SDA: R3.2, TP7.1 (1_1), U1.27 (PC4), U4.7 (SDA)

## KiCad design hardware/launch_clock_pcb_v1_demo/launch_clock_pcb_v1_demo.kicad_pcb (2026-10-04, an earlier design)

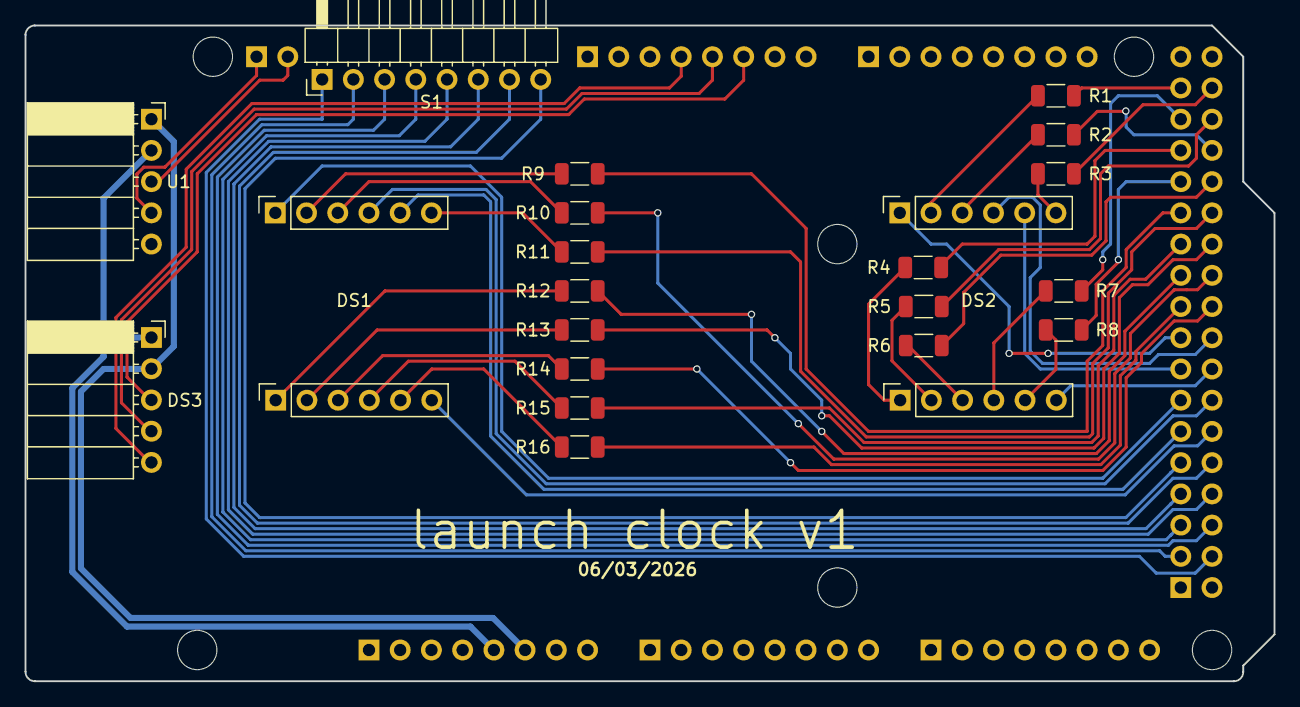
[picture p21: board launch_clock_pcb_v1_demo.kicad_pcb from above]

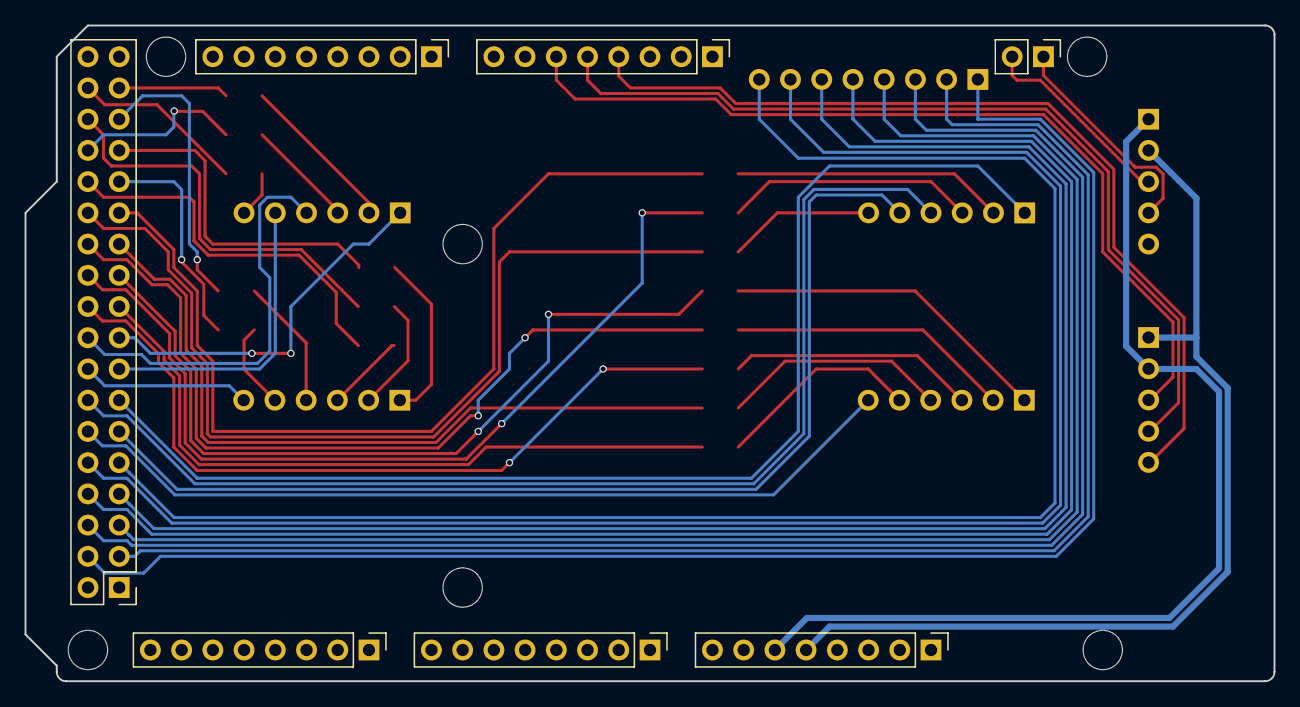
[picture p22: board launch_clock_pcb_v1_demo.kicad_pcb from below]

Board: 2 copper layers, 101.6 x 53.3 mm, 34 parts (7 on the bottom side), 55 nets.

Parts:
DS1, DS2: launch_clock_7seg
DS3: PinSocket_1x05_P2.54mm_Horizontal
J1: Power; PinHeader_1x08_P2.54mm_Vertical
J2: PWM; PinHeader_1x02_P2.54mm_Vertical
J3, J5: Analog; PinHeader_1x08_P2.54mm_Vertical
J4: PWM; PinHeader_1x08_P2.54mm_Vertical
J6: Communication; PinHeader_1x08_P2.54mm_Vertical
J7: Digital; PinHeader_2x18_P2.54mm_Vertical
MH1, MH2, MH3, MH4, MH5, MH6: MountingHole_3.2mm
R1, R2, R3, R4, R5, R6, R7, R8, R9, R10, R11, R12, R13, R14, R15, R16: 220; R_1206_3216Metric
S1: PinHeader_1x08_P2.54mm_Horizontal
U1: PinSocket_1x05_P2.54mm_Horizontal

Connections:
+5V: DS3.1 (VCC), J1.5, J7.35, J7.36, U1.2 (VCC)
/22: J7.33, R1.1
/23: J7.34, R3.1
/24: J7.31, R7.2
/25: J7.32, R5.2
/26: J7.29, R4.2
/27: J7.30, R2.1
/28: J7.27, R8.2
/29: J7.28, R6.2
/30: J7.25, R9.1
/31: J7.26, R11.1
/32: J7.23, R15.2
/33: J7.24, R13.2
/34: J7.21, R12.2
/35: J7.22, R10.1
/36: J7.19, R16.2
/37: J7.20, R14.2
/38: DS2.1 (d0), J7.17
/39: DS2.4 (d1), J7.18
/40: DS2.5 (d2), J7.15
/41: DS2.12 (d3), J7.16
/42: DS1.1 (d0), J7.13
/43: DS1.4 (d1), J7.14
/47: J7.10, S1.7 (c3)
/48: J7.7, S1.6 (c2)
/49: J7.8, S1.5 (c1)
/50: J7.5, S1.4 (r4)
/51: J7.6, S1.3 (r3)
/53: J7.4, S1.1 (r1)
/*2: DS3.3 (DIN), J4.6
/*3: DS3.4 (CS), J4.5
/*4: DS3.5 (CLK), J4.4
/*44: DS1.5 (d2), J7.11
/*45: DS1.12 (d3), J7.12
/*46: J7.9, S1.8 (c4)
/*52: J7.3, S1.2 (r2)
/SCL/21: J2.1, J6.8, U1.4 (SCL)
/SDA/20: J2.2, J6.7, U1.3 (SDA)
GND: DS3.2 (GND), J1.6, J1.7, J7.1, J7.2, U1.1 (GND)
unnamed: DS1.2 (A), R9.2
unnamed: DS1.6 (B), R11.2
unnamed: DS1.10 (C), R15.1
unnamed: DS1.8 (D), R13.1
unnamed: DS1.9 (DP), R14.1
unnamed: DS1.7 (E), R12.1
unnamed: DS1.3 (F), R10.2
unnamed: DS1.11 (G), R16.1
unnamed: DS2.2 (A), R1.2
unnamed: DS2.6 (B), R3.2
unnamed: DS2.10 (C), R7.1
unnamed: DS2.8 (D), R5.1
unnamed: DS2.9 (DP), R6.1
unnamed: DS2.7 (E), R4.1
unnamed: DS2.3 (F), R2.2
unnamed: DS2.11 (G), R8.1

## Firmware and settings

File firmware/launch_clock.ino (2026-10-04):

#include <Wire.h>
#include <RTClib.h>
#include <Keypad.h>
#include <LedControl.h>
#include <EEPROM.h>
#include <avr/sleep.h>
#include <avr/power.h>
#include <avr/pgmspace.h>

RTC_DS3231 rtc;
/* L_Zero and launchTime ostensibly store the same time but serve distinct purposes. L_Zero gets the time stored in EEPROM written to it within the setup function. 
The hardcoded time in the declaration is used if no time is found in EEPROM. L_Zero is updated when the launch date/time are reset, and should always reflect what 
is stored in EEPROM. Conversely, launchTime is the variable used in calculating time until launch, and is in unix time. It starts with the same time as in L_Zero 
(in unix), but can differ from L_Zero if the countdown is paused.*/
uint16_t L_Zero[6] = {2026, 4, 1, 18, 35, 12}; // Format: {Y, M, D, h, m, s}.
uint32_t launchTime; // non-persistent value used for calculations
uint16_t CT_Set[6] = {2000, 1, 1, 0, 0, 0};

const uint8_t autoCancel = 10; // time mode autocancel (in seconds)
const uint16_t blinkInterval = 500; // matrix blink rate (in milliseconds)
uint8_t brightnessMode = 1; // initial brightness mode

// boolean flags to create state machine
bool hourMode = false, displayOn = true;
bool pauseActive = false, exitPause = false, countDelayed = false;
bool showTimeActive = false, exitShowTime = false, bypassShowTime = false;
bool showLDActive = false, exitShowLD = false, showLTActive = false, exitShowLT = false, ignoreNextShow = false;
bool showVersionActive = false, exitShowVersion = false;
bool CT_Reset = false, CD_Reset = false, LD_Reset = false, LT_Reset = false;
bool errorModeActive = false, timeValid;
bool bypass = true, bypassCT = false, resetMatrix = false;
const uint8_t* lastMatrix = nullptr;
const uint8_t* lastModeMatrix = nullptr;
uint32_t lastUpdate = 0, lastDiff = 0;

// Code uses Arduino Uno pin numbering, even though standalone ATmega328 is used
const uint8_t DIN_PIN = A0, CLK_PIN = A1, CS_PIN = A2; // MAX7219 SPI pins
/*On the V3 PCB:
  The row and column pins for the keypad change. They should look as follows:
  const uint8_t rowPins[4] = {9, 8, 7, 6}, colPins[4] = {5, 4, 3, 2}, ...
*/
const uint8_t rowPins[4] = {2, 3, 4, 5}, colPins[4] = {6, 7, 8, 9}, unusedPins[7] = {10, 11, 12, 13, A4, 0, 1};

const char keys[4][4] = {
  { '1', '2', '3', 'A' },
  { '4', '5', '6', 'B' },
  { '7', '8', '9', 'C' },
  { '*', '0', '#', 'D' }
};

// PROGMEM bitmaps for dot matrix status glyphs
const uint8_t L_Plus[8] PROGMEM = {
  0b10000000,
  0b10000000,
  0b10000000,
  0b10000010,
  0b10000111,
  0b10000010,
  0b10000000,
  0b11110000
};
const uint8_t L_Minus[8] PROGMEM= {
  0b10000000,
  0b10000000,
  0b10000000,
  0b10000000,
  0b10000111,
  0b10000000,
  0b10000000,
  0b11110000
};
const uint8_t L_Pause[8] PROGMEM = {
  0b10000000,
  0b10000000,
  0b10000000,
  0b10000101,
  0b10000101,
  0b10000101,
  0b10000000,
  0b11110000
};
const uint8_t CT_Matrix[8] PROGMEM = {
  0b11100111,
  0b10000010,
  0b10000010,
  0b10000010,
  0b10000010,
  0b10000010,
  0b10000010,
  0b11100010
};
const uint8_t CD_Matrix[8] PROGMEM = {
  0b11101110,
  0b10001001,
  0b10001001,
  0b10001001,
  0b10001001,
  0b10001001,
  0b10001001,
  0b11101110
};
const uint8_t LT_Matrix[8] PROGMEM = {
  0b10011111,
  0b10000100,
  0b10000100,
  0b10000100,
  0b10000100,
  0b10000100,
  0b10000100,
  0b11110100
};
const uint8_t LD_Matrix[8] PROGMEM = {
  0b10001110,
  0b10001001,
  0b10001001,
  0b10001001,
  0b10001001,
  0b10001001,
  0b10001001,
  0b11101110
};
const uint8_t ER_Matrix[8] PROGMEM = {
  0b11101111,
  0b10001001,
  0b10001001,
  0b10001110,
  0b11101010,
  0b10001001,
  0b10001001,
  0b11101001
};
const uint8_t V_Matrix[8] PROGMEM = {
  0b01000010,
  0b01000010,
  0b01000010,
  0b01000010,
  0b00100100,
  0b00100100,
  0b00100100,
  0b00011000
};
const uint8_t matrixOFF[8] PROGMEM = {
  0b00000000,
  0b00000000,
  0b00000000,
  0b00000000,
  0b00000000,
  0b00000000,
  0b00000000,
  0b00000000
};
const uint8_t displayIntensity[3][2] = {{2,0},{8,2},{15,5}}; // LedControl brightness values mapping to brightnessMode 0,1,2

// used for writing to displays
uint8_t dispVals[2][4] = {{0, 0, 0, 0},{0, 0, 0, 0}};
bool dispDP[2][4]  = {{false, true, false, true},{false, true, false, false}};
uint8_t prevDispVals[2][4] = {{11,11,11,11},{11,11,11,11}};  // 11 to force initial update
bool prevDispDP[2][4]   = {{true,true,true,true},{true,true,true,true}};

Keypad keypad = Keypad(makeKeymap(keys), rowPins, colPins, 4, 4);
LedControl lc = LedControl(DIN_PIN, CLK_PIN, CS_PIN, 2);
ISR(PCINT2_vect) {} // for sleep mode

void updateMode(char mode, bool forceRecalc = true); // forward declaration to make compiler happy :)

void turnOffDisplays() { // sets displays values to off (but does not update the displays)
  for (uint8_t i = 0; i < 4; i++) {
      dispVals[0][i] = 10;
      dispVals[1][i] = 10;
      dispDP[0][i] = false;
      dispDP[1][i] = false;
    }
}
void goToSleep() {
  /* On V3 PCB:
    Make sure RTC SDA and SCL lines are written low prior to turning off the RTC power GPIO pin. This is mandatory. Wire.h pulls them high all the time, so
     that may need to be disabled before writing pins low (so "Wire.end()").
    Make sure CP2102N RX and TX lines are both powered low prior to opening the load switch. Make sure you are certain these are low. */
  displayMatrix(matrixOFF);
  lc.shutdown(0, true);
  lc.shutdown(1, true);

  for (uint8_t i = 0; i < 4; i++) {
    pinMode(rowPins[i], INPUT);
    pinMode(colPins[i], INPUT);
  }
  pinMode(colPins[0], OUTPUT);
  digitalWrite(colPins[0], HIGH);
  pinMode(colPins[1], OUTPUT);
  digitalWrite(colPins[1], HIGH);
  pinMode(colPins[2], OUTPUT);
  digitalWrite(colPins[2], HIGH);
  pinMode(colPins[3], OUTPUT);
  digitalWrite(colPins[3], LOW);
  pinMode(rowPins[0], INPUT_PULLUP);

  while (digitalRead(rowPins[0]) == LOW) {
  }

  PCIFR  |= _BV(PCIF2);
  PCMSK2  = _BV(PCINT18);
  PCICR  |= _BV(PCIE2);
  uint8_t oldADCSRA = ADCSRA;
  ADCSRA = 0;
  power_all_disable();
  set_sleep_mode(SLEEP_MODE_PWR_DOWN);
  sleep_enable();
  noInterrupts();
  MCUCR = _BV(BODS) | _BV(BODSE);
  MCUCR = _BV(BODS);
  interrupts();

  sleep_cpu(); // sleeps until 'A' key is pressed

  sleep_disable();
  PCICR  = 0;
  PCMSK2 = 0;
  power_all_enable();
  ADCSRA = oldADCSRA;

  lc.shutdown(0, false);
  lc.shutdown(1, false);
  memset(prevDispVals, 11, sizeof(prevDispVals)); // force update
  displayOn = true;
  bypass = false;
  findMode();
}

void errorMode(String str) { // controls behavior of all error states
  errorModeActive = true;
  displayMatrix(ER_Matrix);
  resetMatrix = false;
  turnOffDisplays();
  refreshDisplays();
  if (str == "ND" || str == "RTC") { // "ND"  and "RTC" are hard errors, and cannot be escaped. Device must be restarted or reset button be pressed.
    turnOffDisplays();
    if (str == "ND") {
      dispVals[1][2] = 0;
      dispVals[1][3] = 0;
    } else if (str == "RTC") {
      dispVals[1][2] = 0;
      dispVals[1][3] = 1;
    }
    refreshDisplays();
    uint32_t lastBlink = millis();
    bool matrixOn = true;
    while (true) {
      if (millis() - lastBlink >= blinkInterval) {
        matrixOn = !matrixOn;
        lastBlink = millis();
        if (matrixOn) {
          displayMatrix(ER_Matrix);
        } else {
          displayMatrix(matrixOFF);
        }
      }
    }
  }
  do {
    char key = keypad.getKey();
    if (resetMatrix) {
      turnOffDisplays();
      refreshDisplays();
      displayMatrix(ER_Matrix);
      resetMatrix = false;
    }
    if (key == 'C' && str == "CT") {
      resetCurrentTime();
      resetMatrix = true;
    }
    if (key == 'C' && str == "CD") {
      resetCurrentDate();
      resetMatrix = true;
    }
    if (key == '*' && (str == "LD")) {
      resetLaunchDate();
      resetMatrix = true;
    }
    if (key == '#' && (str == "LT")) {
      resetLaunchTime();
      resetMatrix = true;
    }
    delay(1);
  } while (!timeValid);
  ignoreNextShow = true;
  errorModeActive = false;
}
uint32_t toUnix(uint16_t T[]) { // converts passed time array to unix time and returns it
  DateTime launch(T[0], T[1], T[2], T[3], T[4], T[5]);
  uint32_t t = launch.unixtime();
  return(t);
}
bool checkTimeValid(uint16_t T[]) { // Checks passed array-form time/date are valid (and between years 2000 to 2100)
  if (T[0] < 2000 || T[0] >= 2100) return false;
  if (T[1] < 1 || T[1] > 12) return false;
  if (T[1] == 1 || T[1] == 3 || T[1] == 5 || T[1] == 7 || T[1] == 8 || T[1] == 10 || T[1] == 12) {
    if (T[2] > 31) return false;
  } else if (T[1] != 2) {
    if (T[2] > 30) return false;
  } else {
    if (T[0] % 400 == 0 || (T[0] % 4 == 0 && T[0] % 100 != 0)) { // leap year handling
      if (T[2] > 29) return false;
    } else {
      if (T[2] > 28) return false;
    }
  }
  if (T[2] < 1) return false;
  if (T[3] > 23) return false;
  if (T[4] > 59) return false;
  if (T[5] > 59) return false;
  return true;
}

void keypadEvent(KeypadEvent key) { // contains all state machine logic via switch and if/else statements. Organized into PRESSED, HOLD, and RELEASED states, and then by specific key
  if (LT_Reset || LD_Reset || CT_Reset || CD_Reset || !timeValid) return;
  switch (keypad.getState()) {
    case PRESSED:
      if (key == 'C' && pauseActive) {
        pauseActive = false;
        exitPause = true;
      }
      if (key == 'D' && pauseActive) exitPause = true;
      break;
    
    case HOLD:
      if (key == '0' && !pauseActive && !showTimeActive && !showLDActive && !showLTActive && displayOn) {
        showVersion();
      }
      if (key == 'A' && !pauseActive && !showTimeActive && !showLDActive && !showLTActive && bypass && displayOn) {
        displayOn = false;
        turnOffDisplays();
        refreshDisplays();
        displayMatrix(matrixOFF);
        // turns off displays but doesn't enter sleep mode until key is released to prevent triggering interrupt
      }
      if (key == 'C' && !pauseActive && displayOn && !showTimeActive && !showLDActive && !showLTActive) {
        resetCurrentTime();
        bypassShowTime = true;
      }
      if (key == 'D' && !pauseActive) {
        launchTime = toUnix(L_Zero);
        lc.setLed(1, 7, 7, false);
        countDelayed = false;
        exitPause = true;
        findMode();
      }
      if (key == '#' && !pauseActive && displayOn && !showTimeActive && !showLDActive && !showLTActive) {
        resetLaunchTime();
        exitShowLT = true;
      }
      if (key == '*' && !pauseActive && displayOn && !showTimeActive && !showLDActive && !showLTActive) {
        resetLaunchDate();
        exitShowLD = true;
      }
      break;
    
    case RELEASED:
      if (key == '0' && !pauseActive && !showTimeActive && !showLDActive && !showLTActive) {
        if (showVersionActive) exitShowVersion = true;
      }
      if (key == 'A' && !pauseActive && !showTimeActive && !showLDActive && !showLTActive) {
        if (!displayOn){
          findMode();
        } else if (!bypass) {
          bypass = true;
        } else {
          brightnessMode++;
          if (brightnessMode == 3) brightnessMode = 0;
          for (int i = 0; i < 2; i++) {
            lc.setIntensity(i, displayIntensity[brightnessMode][i]);
          }
          updateMode(hourMode ? 'H' : 'D', false);
        }
      }
      if (key == 'B' && !pauseActive && !showTimeActive && !showLDActive && !showLTActive && displayOn) {
      hourMode = !hourMode;
      updateMode(hourMode ? 'H' : 'D', false);
      }
      if (key == 'C' && !pauseActive && !showLDActive && !showLTActive && displayOn) {
        if (bypassCT) {
          bypassCT = false;
          exitShowLD = false;
          exitShowLT = false;
        } else {
          if (exitPause) exitPause = false;
          else if (bypassShowTime) bypassShowTime = false;
          else if (!showTimeActive) {
            showTime();
          } else {
            exitShowTime = true;
          }
        }
      }
      if (key == 'D') {
        if (!pauseActive && !exitPause && !showTimeActive && !showLDActive && !showLTActive && displayOn) pauseCountdown();
        else {
          exitPause = false;
          pauseActive = false;
        } 
      }
      if (key == '*' && !pauseActive && !showTimeActive && displayOn) {
        if (ignoreNextShow) {
          ignoreNextShow = false;
        } else {
          if (showLTActive) exitShowLT = true;
          if (!showLDActive && !exitShowLD) {
            showLaunchDate();
          } else if (showLDActive && !exitShowLD) exitShowLD = true;
          else {
            showLDActive = false;
            exitShowLD = false;
          }
        }
      }
      if (key == '#' && !pauseActive && !showTimeActive && displayOn) {
        if (ignoreNextShow) {
          ignoreNextShow = false;
        } else {
          if (showLDActive) exitShowLD = true;
          if (!showLTActive && !exitShowLT) {
            showLaunchTime();
          } else if (showLTActive && !exitShowLT) exitShowLT = true;
          else {
            showLTActive = false;
            exitShowLT = false;
          }
        }
      }
      break;
    default:
      break;
  }
}
void findMode() {
  if (!displayOn) {
    goToSleep();
  } else {
    updateMode(hourMode ? 'H' : 'D');
  }
}

void resetCurrentTime() { // reset the current time on the RTC via keypad.
  CT_Reset = true;
  displayMatrix(CT_Matrix);
  turnOffDisplays();
  dispDP[0][3] = true;
  dispDP[1][1] = true;
  uint32_t lastBlink = millis();
  bool matrixOn = true;

  String inpString = "";
  bool inputDone = false;

  while (!inputDone) {
    char key = keypad.getKey();
    if (key) {
      switch (key) {
        case '0' ... '9':
          if (inpString.length() < 6) {
            inpString += key;
            showInputPreview(inpString);
          }
          break;

        case 'B':
          inpString = "";
          showInputPreview(inpString);
          break;
          
        case 'C':
          if (inpString.length() == 6) {
            parseAndSet_CT(inpString);
            inputDone = true;
          } else {
            CT_Reset = false;
            resetMatrix = true;
            return;
            }
          break;

        case 'D':
          if (inpString.length() > 0) {
            inpString.remove(inpString.length() - 1);
            showInputPreview(inpString);
          }
          break;
      }
    }    
    if (millis() - lastBlink >= blinkInterval) {
      matrixOn = !matrixOn;
      lastBlink = millis();
      if (matrixOn) {
        displayMatrix(CT_Matrix);
      } else {
        displayMatrix(matrixOFF);
      }
    }
    refreshDisplays();
    delay(10);
  }
  CT_Reset = false;
  timeValid = checkTimeValid(CT_Set);
  if (errorModeActive) return;
  if (!timeValid) errorMode("CT");
  countDelayed = false;
  DateTime newTime(CT_Set[0], CT_Set[1], CT_Set[2], CT_Set[3], CT_Set[4], CT_Set[5]); // create datetime with new time
  rtc.adjust(newTime);
  findMode();
}
void resetCurrentDate() {
  // This function is only called if loss of RTC power is detected. Not accessible in standard UI
  CD_Reset = true;
  displayMatrix(CD_Matrix);
  turnOffDisplays();
  dispDP[0][3] = true;
  dispDP[1][1] = true;
  uint32_t lastBlink = millis();
  bool matrixOn = true;

  String inpString = "";
  bool inputDone = false;

  while (!inputDone) {
    char key = keypad.getKey();
    if (key) {
      switch (key) {
        case '0' ... '9':
          if (inpString.length() < 8) {
            inpString += key;
            showInputPreview(inpString);
          }
          break;
          
        case 'C':
          if (inpString.length() == 8) {
            parseAndSet_CD(inpString);
            inputDone = true;
          }
          break;
        
        case 'D':
          if (inpString.length() > 0) {
            inpString.remove(inpString.length() - 1);
            showInputPreview(inpString);
          }
          break;
      }
    }
    if (millis() - lastBlink >= blinkInterval) {
      matrixOn = !matrixOn;
      lastBlink = millis();
      if (matrixOn) {
        displayMatrix(CD_Matrix);
      } else {
        displayMatrix(matrixOFF);
      }
    }
    refreshDisplays();
    delay(10);
  }
  CD_Reset = false;
  timeValid = checkTimeValid(CT_Set);
  if (errorModeActive) return;
  if (!timeValid) errorMode("CD");
}
void resetLaunchDate() { // reset programmed launch date via keypad
  LD_Reset = true;
  bool addDay = false; // controls day nudging
  uint16_t newL_Zero[6] = {L_Zero[0], L_Zero[1], L_Zero[2], L_Zero[3], L_Zero[4], L_Zero[5]};
  uint8_t daysAdded = 0;
  bool validity;
  displayMatrix(LD_Matrix);
  turnOffDisplays();
  dispDP[0][3] = true;
  dispDP[1][1] = true;
  uint32_t lastBlink = millis();
  bool matrixOn = true;

  String inpString = "";
  bool inputDone = false;

  while (!inputDone) {
    char key = keypad.getKey();
    if (key) {
      switch (key) {
        case '0' ... '9':
          if (addDay) break;
          if (inpString.length() < 8) {
            inpString += key;
            showInputPreview(inpString);
          }
          break;
        
        case 'A':
          if (!addDay) { // launch date can be nudged foward by day up to a week using 'A' key
            turnOffDisplays();
            addDay = true;
            inpString = "";
          }
          ++daysAdded;
          if (daysAdded > 7) {
            daysAdded = 7;
            break;
          }
          dispVals[1][3] = daysAdded;
          refreshDisplays();
          ++newL_Zero[2];
          validity = checkTimeValid(newL_Zero);
          if (!validity) {
            newL_Zero[2] = 1;
            ++newL_Zero[1];
          }
          validity = checkTimeValid(newL_Zero);
          if (!validity) {
            newL_Zero[1] = 1;
            ++newL_Zero[0];
          }
          break;
        
        case 'B':
          if (addDay) {
            addDay = false;
            daysAdded = 0;
            for (int i = 0; i < 6; i++) {
              newL_Zero[i] = L_Zero[i];
            }
            dispVals[1][3] = 10;
            dispDP[0][3] = true;
            dispDP[1][1] = true;
            refreshDisplays();
          } else {
            inpString = "";
            showInputPreview(inpString);
          }
          break;
        
        case 'C':
          if (addDay) {
            LD_Reset = false;
            resetMatrix = true;
            bypassCT = true;
            return;
          } else break;

        case '*':
          if (addDay) {
            validity = checkTimeValid(newL_Zero);
            if (!validity) errorMode("ND");
            for (int i = 0; i < 6; i++) {
              L_Zero[i] = newL_Zero[i];
            }
            EEPROM.put(0, L_Zero);
            launchTime = toUnix(L_Zero);
            LD_Reset = false;
            resetMatrix = true;
            return;
          }
          if (inpString.length() == 8) {
            parseAndSetL_Zero(inpString);
            inputDone = true;
          } else {
            LD_Reset = false;
            resetMatrix = true;
            return;
          }
          break;
        
        case 'D':
          if (addDay) {
            for (int i = 0; i < 6; i++) {
              newL_Zero[i] = L_Zero[i];
            }
            daysAdded = 0;
            dispVals[1][3] = 0;
            refreshDisplays();
            break;
          }
          if (inpString.length() > 0) {
            inpString.remove(inpString.length() - 1);
            showInputPreview(inpString);
          }
          break;
      }
    }
    if (millis() - lastBlink >= blinkInterval) {
      matrixOn = !matrixOn;
      lastBlink = millis();
      if (matrixOn) {
        displayMatrix(LD_Matrix);
      } else {
        displayMatrix(matrixOFF);
      }
    }
    refreshDisplays();
    delay(10);
  }
  LD_Reset = false;
  timeValid = checkTimeValid(L_Zero);
  if (errorModeActive) return;
  if (!timeValid) errorMode("LD");
  launchTime = toUnix(L_Zero);
  countDelayed = false;
  findMode();
}
void resetLaunchTime() { // reset programmed launch date via keypad. Close to identical to resetLaunchDate without nudging
  LT_Reset = true;
  displayMatrix(LT_Matrix);
  turnOffDisplays();
  dispDP[0][3] = true;
  dispDP[1][1] = true;
  uint32_t lastBlink = millis();
  bool matrixOn = true;
  
  String inpString = "";
  bool inputDone = false;

  while (!inputDone) {
    char key = keypad.getKey();
    if (key) {
      switch (key) {
        case '0' ... '9':
          if (inpString.length() < 6) {
            inpString += key;
            showInputPreview(inpString);
          }
          break;
        
        case 'B':
          inpString = "";
          showInputPreview(inpString);
          break;
          
        case '#':
          if (inpString.length() == 6) {
            parseAndSetL_Zero(inpString);
            inputDone = true;
          } else {
            LT_Reset = false;
            resetMatrix = true;
            return;
            }
          break;

        case 'D':
          if (inpString.length() > 0) {
            inpString.remove(inpString.length() - 1);
            showInputPreview(inpString);
          }
          break;
      }
    }
    if (millis() - lastBlink >= blinkInterval) {
      matrixOn = !matrixOn;
      lastBlink = millis();
      if (matrixOn) {
        displayMatrix(LT_Matrix);
      } else {
        displayMatrix(matrixOFF);
      }
    }
    refreshDisplays();
    delay(10);
  }
  LT_Reset = false;
  timeValid = checkTimeValid(L_Zero);
  if (errorModeActive) return;
  if (!timeValid) errorMode("LT");
  launchTime = toUnix(L_Zero);
  countDelayed = false;
  findMode();
}
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
void loop() {
  keypad.getKey();

  if (displayOn) {
    if (millis() - lastUpdate >= 1000) { // refresh displayed time every second
      findMode();
      lastUpdate = millis();
    }
    refreshDisplays();
  }
}

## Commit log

2026-10-04 Prepare repository for public release
    [.step, launch_clock_pcb_v1.kicad_pcb, launch_clock_pcb_v1.kicad_sch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]
2026-10-04 Fix custom KiCad library paths
    [.step, launch_clock_pcb_v1_demo.kicad_pcb, launch_clock_pcb_v1_demo.kicad_sch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]
